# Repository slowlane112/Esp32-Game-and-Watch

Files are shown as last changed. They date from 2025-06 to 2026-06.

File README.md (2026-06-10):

# Esp32-Game-and-Watch

Esp32‑Game‑and‑Watch is a project for recreating classic Game & Watch handhelds using an ESP32 microcontroller, 3D‑printed cases, and simple electronics. 

It currently supports most single screen and multi screen Game & Watch titles, making it easy to recreate a wide range of the original handhelds.

## Latest Updates

- Updated the codebase to work with ESP‑IDF 6.0
- Added support for ST7789V LCD screens

<table>
<tr>
<td><strong>Demos</strong></td>
</tr>
<tr>
<td>
	<p><strong>Single Screen</strong></p>
	<p><a href="https://github.com/slowlane112/Esp32-Game-and-Watch/tree/main/gandw_demo_single_screen">
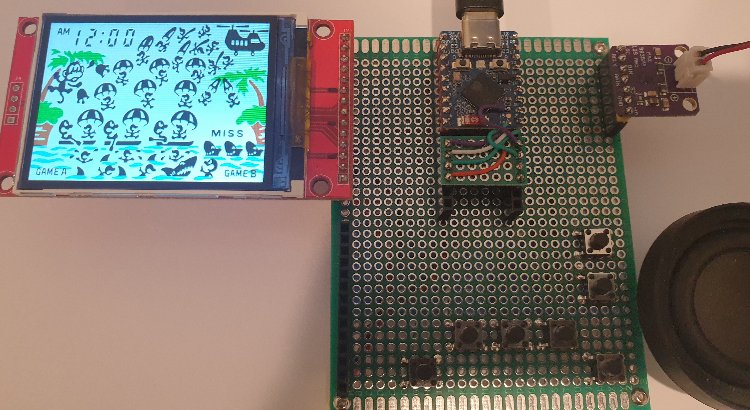
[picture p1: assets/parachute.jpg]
Parachute
		
	</a></p>
	<p><a href="https://github.com/slowlane112/Esp32-Game-and-Watch/tree/main/gandw_demo_single_screen">https://github.com/slowlane112/Esp32-Game-and-Watch/tree/main/gandw_demo_single_screen</a></p>
</td>
</tr>
<tr>
<td>
	<p><strong>Multi Screen</strong></p>
	<p><a href="https://github.com/slowlane112/Esp32-Game-and-Watch/tree/main/gandw_demo_multi_screen">
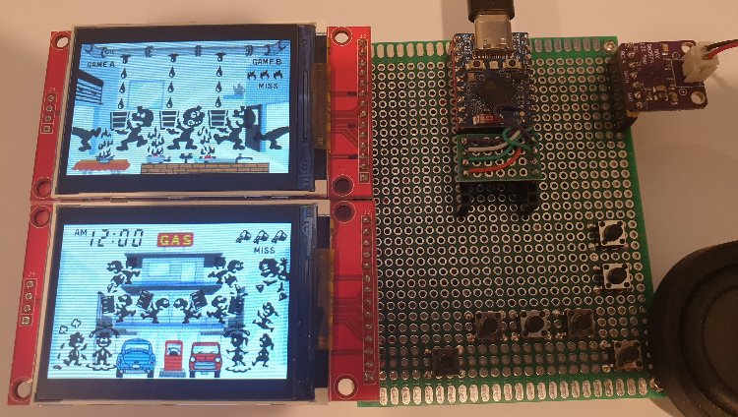
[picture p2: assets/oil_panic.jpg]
Oil Panic
		
	</a></p>
	<p><a href="https://github.com/slowlane112/Esp32-Game-and-Watch/tree/main/gandw_demo_multi_screen">https://github.com/slowlane112/Esp32-Game-and-Watch/tree/main/gandw_demo_multi_screen</a></p>
</td>	
</tr>
</table>

<br>

<table>
<tr>
<td><strong>Single Screen Handhelds</strong></td>
</tr>
<tr>
<td>
	<p><strong>2 Buttons</strong></p>
	<p><a href="https://github.com/slowlane112/Esp32-Game-and-Watch/tree/main/gandw_handheld/README-single_screen_2_button.md">
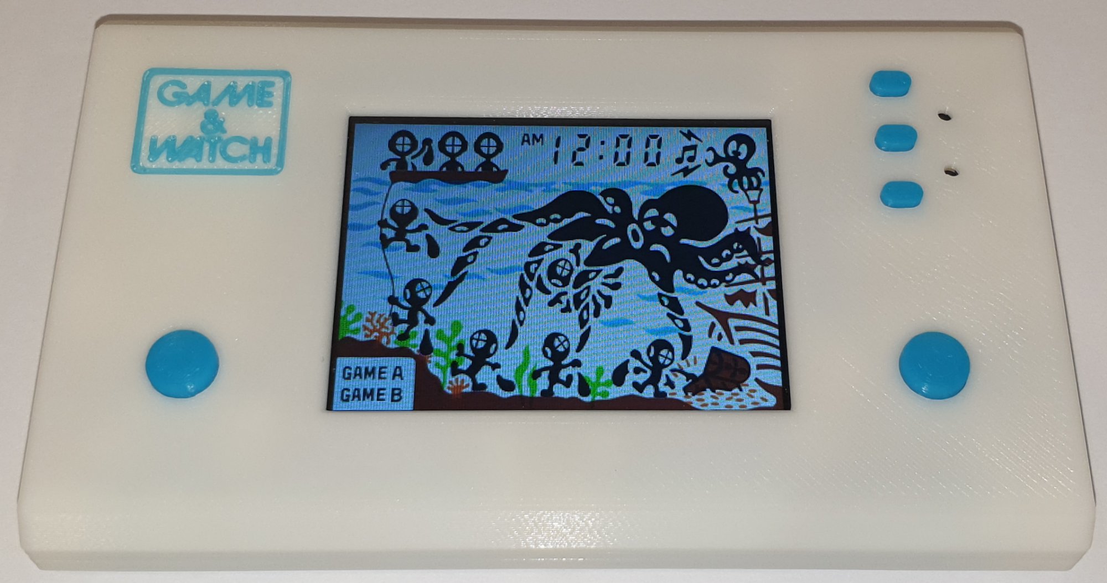
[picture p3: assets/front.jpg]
Single Screen Handheld
		
	</a></p>
	<p><a href="https://github.com/slowlane112/Esp32-Game-and-Watch/tree/main/gandw_handheld/README-single_screen_2_button.md">https://github.com/slowlane112/Esp32-Game-and-Watch/tree/main/gandw_handheld/README-single_screen_2_button.md</a></p>
</td>
</tr>
<tr>
<td>
	<p><strong>4 Buttons</strong></p>
	<p><a href="https://github.com/slowlane112/Esp32-Game-and-Watch/tree/main/gandw_handheld/README-single_screen_4_button.md">
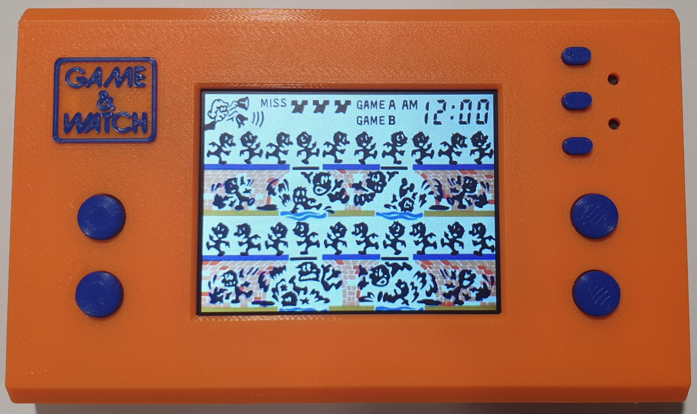
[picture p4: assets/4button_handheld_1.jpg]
Single Screen 4 Button Handheld
		
	</a></p>
	<p><a href="https://github.com/slowlane112/Esp32-Game-and-Watch/tree/main/gandw_handheld/README-single_screen_4_button.md">https://github.com/slowlane112/Esp32-Game-and-Watch/tree/main/gandw_handheld/README-single_screen_4_button.md</a></p>
</td>	
</tr>
</table>

<br>

<table>
<tr>
<td><strong>Multi Screen Handhelds</strong></td>
</tr>
<tr>
<td>
	<p><strong>2 Buttons</strong></p>
	<p><a href="https://github.com/slowlane112/Esp32-Game-and-Watch/tree/main/gandw_handheld/README-multi_screen_2_button.md">
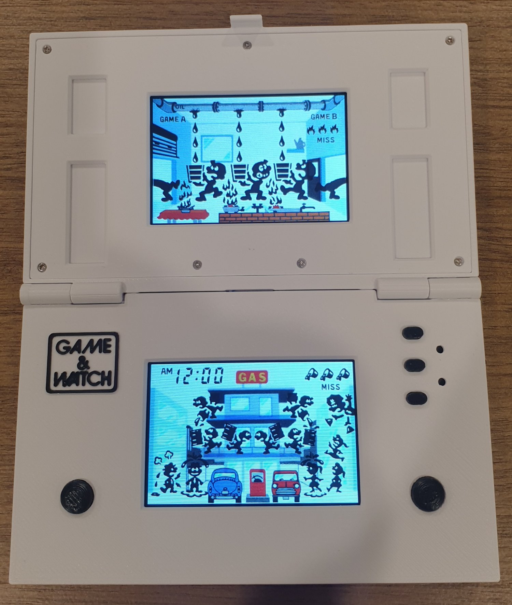
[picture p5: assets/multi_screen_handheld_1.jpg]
Multi Screen Handheld
    	
	</a></p>
	<p><a href="https://github.com/slowlane112/Esp32-Game-and-Watch/tree/main/gandw_handheld/README-multi_screen_2_button.md">https://github.com/slowlane112/Esp32-Game-and-Watch/tree/main/gandw_handheld/README-multi_screen_2_button.md</a></p>
</td>
</tr>
<tr>
<td>
	<p><strong>D-pad</strong></p>
	<p><a href="https://github.com/slowlane112/Esp32-Game-and-Watch/tree/main/gandw_handheld/README-multi_screen_dpad.md">
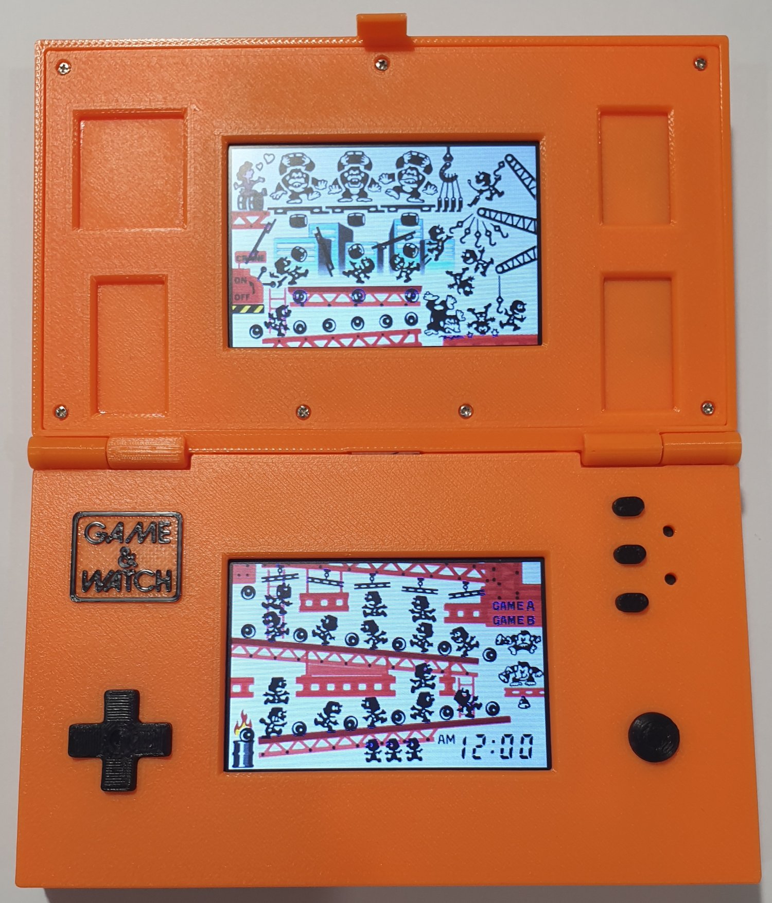
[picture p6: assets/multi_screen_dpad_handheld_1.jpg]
Multi Screen D-pad Handheld
    	
	</a></p>
	<p><a href="https://github.com/slowlane112/Esp32-Game-and-Watch/tree/main/gandw_handheld/README-multi_screen_dpad.md">https://github.com/slowlane112/Esp32-Game-and-Watch/tree/main/gandw_handheld/README-multi_screen_dpad.md</a></p>
</td>	
</tr>
</table>

<br>

<table>
<tr>
<td><strong>Cardputer</strong></td>
</tr>
<tr>
<td>
	<p><strong>Single Screen - Cardputer v1.1 and Cardputer Adv.</strong></p>
	<p><a href="https://github.com/slowlane112/Esp32-Game-and-Watch/tree/main/gandw_cardputer/README-cardputer.md">
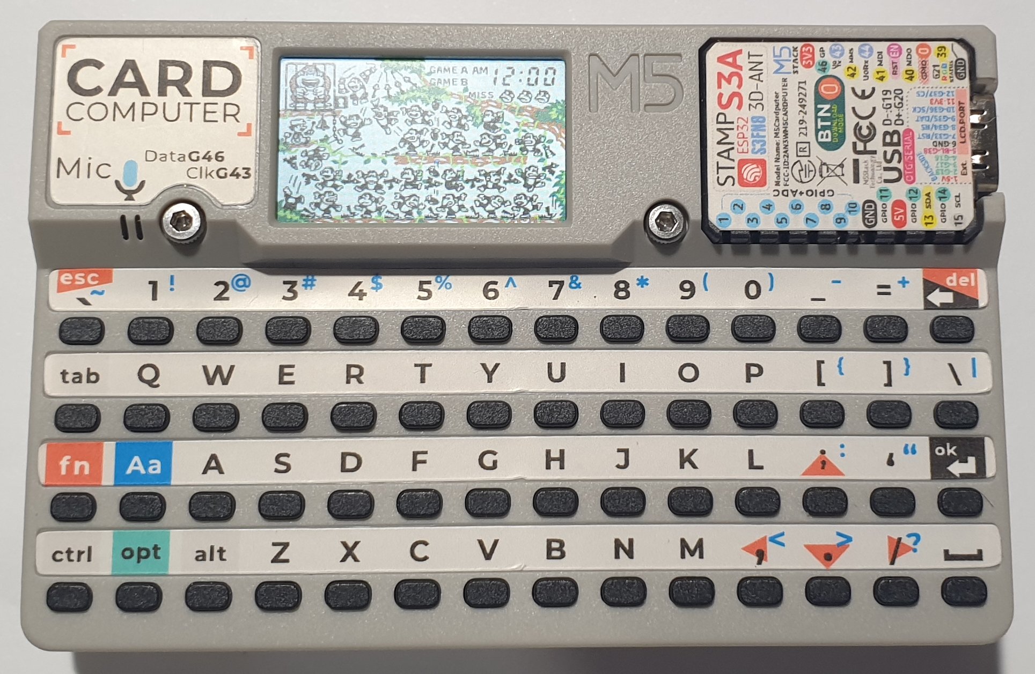
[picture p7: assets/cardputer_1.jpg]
Cardputer
    	
	</a></p>
	<p><a href="https://github.com/slowlane112/Esp32-Game-and-Watch/tree/main/gandw_cardputer/README-cardputer.md">https://github.com/slowlane112/Esp32-Game-and-Watch/tree/main/gandw_cardputer/README-cardputer.md</a></p>
</td>
</tr>
<tr>
<td>
	<p><strong>Multi Screen - Cardputer Adv.</strong></p>
	<p><a href="https://github.com/slowlane112/Esp32-Game-and-Watch/tree/main/gandw_cardputer/README-cardputer_multi_screen.md">
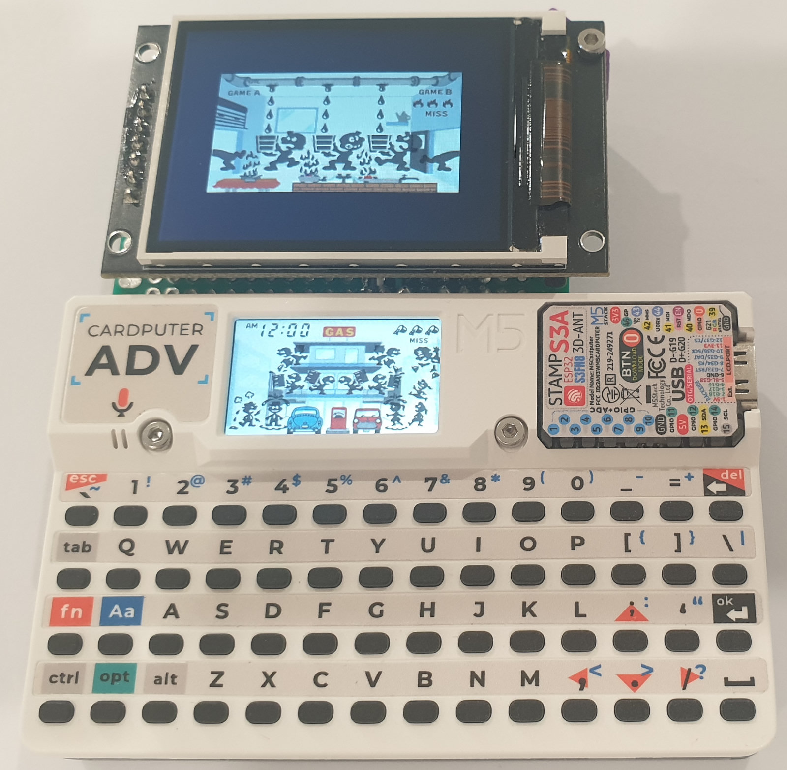
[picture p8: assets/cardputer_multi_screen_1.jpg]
Cardputer
    	
	</a></p>
	<p><a href="https://github.com/slowlane112/Esp32-Game-and-Watch/tree/main/gandw_cardputer/README-cardputer_multi_screen.md">https://github.com/slowlane112/Esp32-Game-and-Watch/tree/main/gandw_cardputer/README-cardputer_multi_screen.md</a></p>
</td>
</tr>
</table>

# Hardware Overview

## ESP32-S3

The project runs on an ESP32‑S3 development board. For handheld builds, the design uses the compact ESP32‑S3 Zero development board.

<table>
<tr>
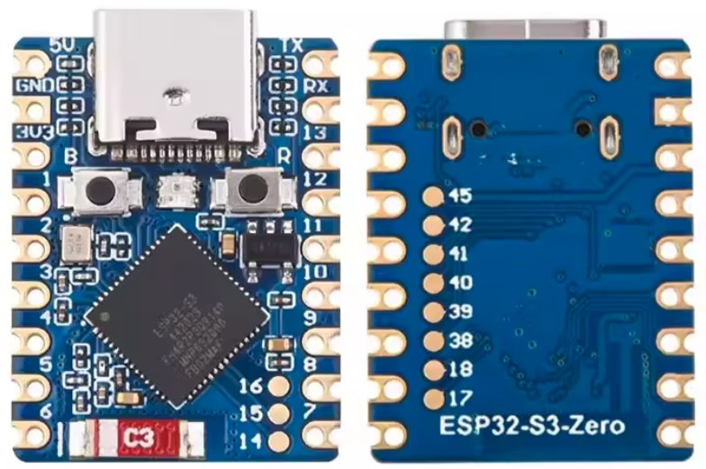
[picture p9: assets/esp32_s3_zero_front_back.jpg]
    <td></td>
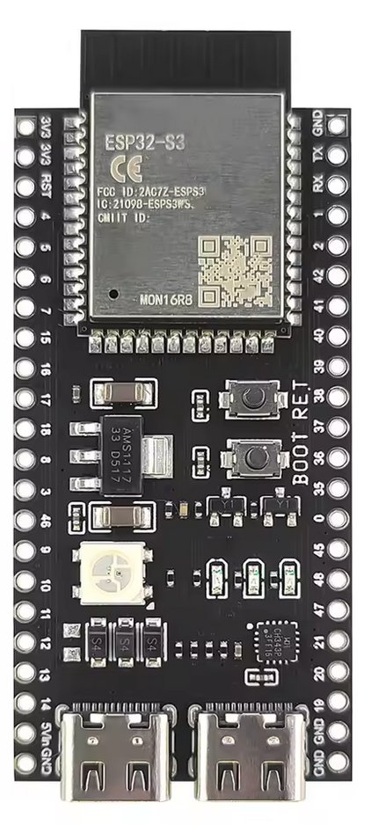
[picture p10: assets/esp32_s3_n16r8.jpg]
    <td></td>
</tr>
<tr>
    <td>ESP32-S3-Zero</td>
    <td>ESP32-S3 N16R8</td>
</tr>
</table>

## Displays

The project supports both the ILI9341 and the newer ST7789V displays. The ST7789V is generally preferred because it supports higher SPI clock speeds and its flex‑cable pin spacing is easier to solder.

<table>
<tr>
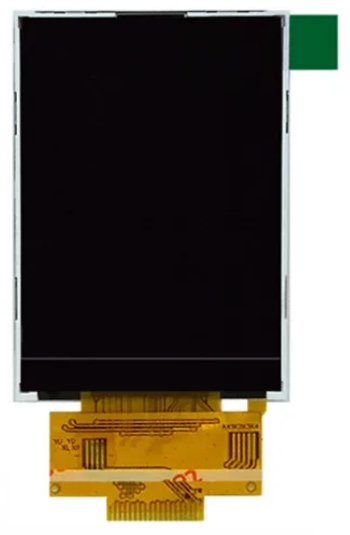
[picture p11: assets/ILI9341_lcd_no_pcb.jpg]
    <td></td>
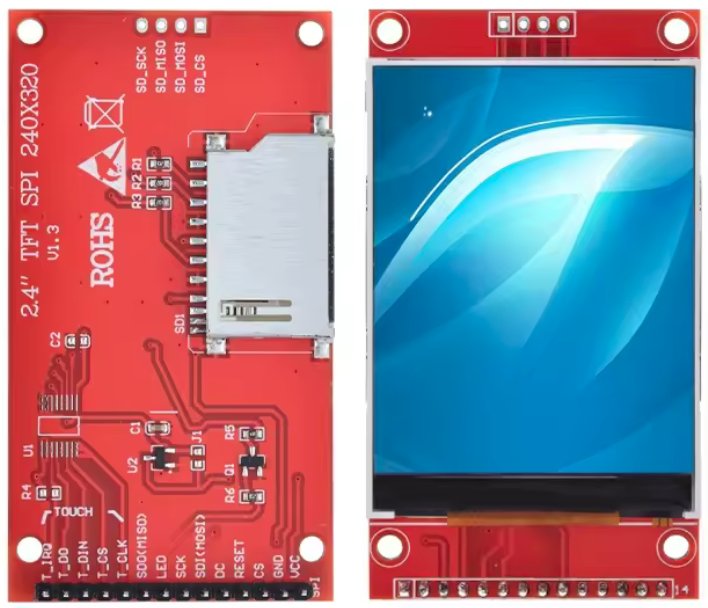
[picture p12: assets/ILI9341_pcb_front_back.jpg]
    <td></td>
</tr>
<tr>
    <td colspan="2">2.4 inch 240 * 320 ILI9341</td>
</tr>
</table>

<table>
<tr>
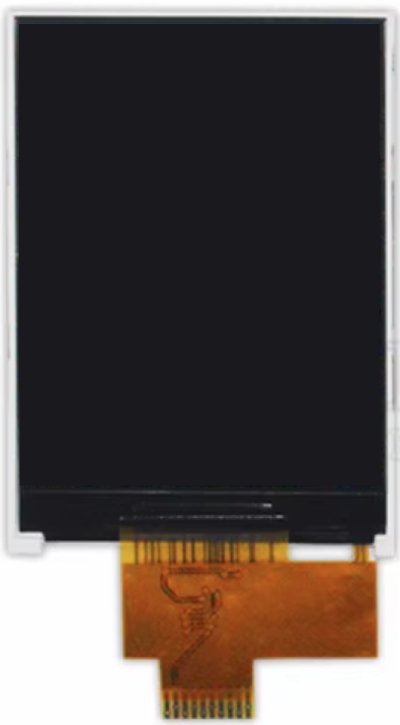
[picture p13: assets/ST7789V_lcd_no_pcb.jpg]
    <td></td>
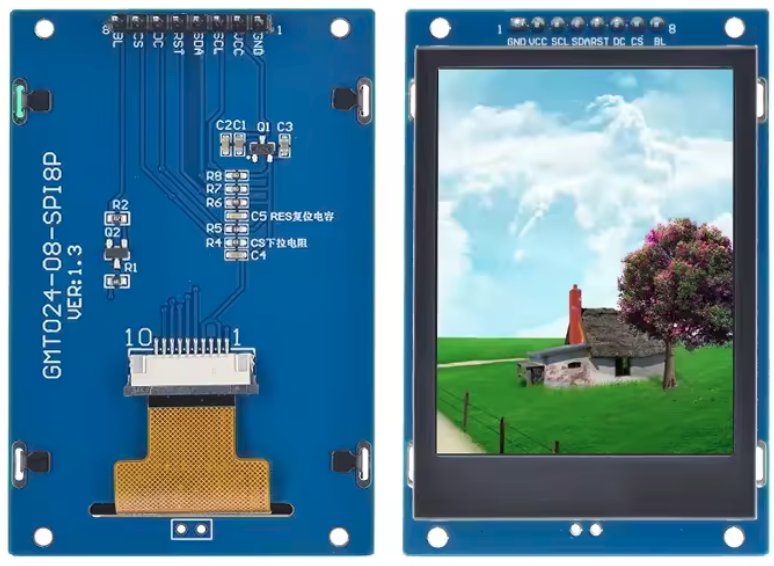
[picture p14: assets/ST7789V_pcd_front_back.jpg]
    <td></td>
</tr>
<tr>
    <td colspan="2">2.4 inch 240 * 320 ST7789V</td>
</tr>
</table>

## Audio

The MAX98357A digital I2S Audio Amplifier Module is used for sound.

<table>
<tr>
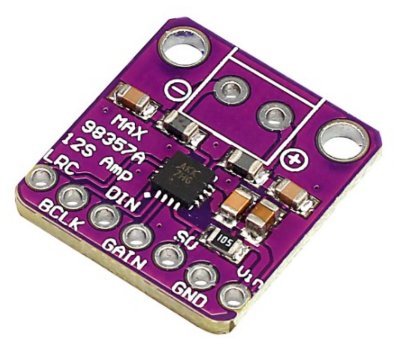
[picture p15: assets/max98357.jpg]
    <td></td>    
</tr>
</table>

# Acknowledgements

## LCD-Game-Emulator

https://github.com/bzhxx/lcd-game-emulator

## Retro-Go

https://github.com/ducalex/retro-go

The LCD-Game-Emulator version used by the project was copied from Retro-Go because it contains additional code to handle the loading of the gw files.

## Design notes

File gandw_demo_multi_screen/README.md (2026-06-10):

# Multi Screen Demo

A demo program using minimal code to run a multi screen game and watch rom on an esp32s3 via LCD Game Emulator.

Oil Panic

# Components
- ESP32-S3-Zero
- Lcd: 240x320 2.4 inch SPI panel with ILI9341 driver
- Audio: Max98357 I2S Amp
- Speaker
- Mini push Buttons

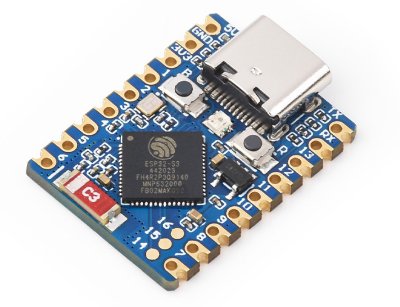
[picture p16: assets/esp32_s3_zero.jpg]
ESP32-S3-Zero

Max98357
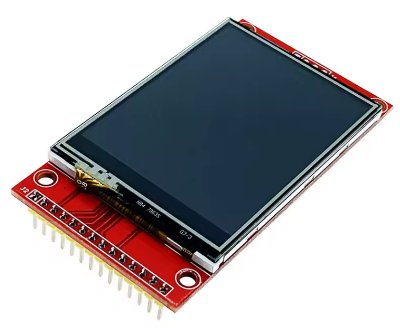
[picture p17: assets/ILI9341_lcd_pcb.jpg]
ILI9341 LCD with pcb

ILI9341 LCD without pcb

# Wiring

## LCD 1
- VCC:		ESP32 3.3v
- GND:		GND
- CS:		GND
- RESET:	GPIO 13
- DC:		GPIO 9
- MOSI:		GPIO 11
- SCK:		GPIO 12
- LED:		ESP32 3.3v

## LCD 2
- VCC:		ESP32 3.3v
- GND:		GND
- CS:		GND
- RESET:	GPIO 39
- DC:		GPIO 38
- MOSI:		GPIO 17
- SCK:		GPIO 18
- LED:		ESP32 3.3v

## Max98357
- VIN:		ESP32 3.3v
- GND:		GND
- LRC (WS):	GPIO 4    
- BCLK:		GPIO 10
- DIN:		GPIO 6

## Buttons
- GAME A:	GPIO 14
- GAME B:	GPIO 5
- TIME:		GPIO 3
- LEFT:		GPIO 2
- RIGHT:	GPIO 1
- ALARM:	GPIO 7
- ACL:		GPIO 8

# Screen Resolution
The ESP32-S3-Zero does not have enough memory to display 2 screens at 320 x 240 resolution.

It does have enough memory to display 2 screens at 320 x 210 resolution.

This is closer to the aspect ratio of the original multi screen game and watch games and what i have used in this project.

This makes the total resolution 320 x 420.

# Roms
The roms must be in .gw format.

These can be created using LCD-Game-Shrinker.

https://github.com/bzhxx/LCD-Game-Shrinker

Below is a link to a guide describing how to use LCD-Game-Shrinker to generate the files.

https://gist.github.com/DNA64/16fed499d6bd4664b78b4c0a9638e4ef

## Additional Steps for Multi Screen Games

LCD Game Shrinker will convert multi screen games into one screen games in portrait mode, so we need to do some additional steps when generating the gw files.

Below are instructions to fix oil panic. All other multi screen games will be similar.

Make a copy of LCD-Game-Shrinker to use for multi screen games.

In the file shrink_it.py set: 
```
gw_height=420
```
In the custom directory, edit gnw_opanic.py

set rom.rotate to false
```
rom.rotate = False
```
Change rom.width_border_ratio from:
```
rom.width_border_ratio = 10/100
```
to:
```
rom.width_border_ratio = 0
```

## Black border between screens
If you run LCD Game Shrinker now there will be a black bar of about 10 pixels between the top and bottom screen.
The gw file will still work ok, but it is a good idea to remove it as it is wasting 10 pixels from the display.

To remove the black bar you need to:

- Extract the artwork zip file.
- Edit the default.lay file to remove the black bar.
- Zip the files again with the updated default.lay file.

In the default.lay file, find the view with the Backgrounds Only. (They usually have a height of 1669).

There is usually more than 1 background view. I am not sure which view LCD Game Shrinker uses so i was just updating all of them. They all use that same values so it is quick to update all of them at the same time.

```
<view name="Backgrounds Only">

<bounds x="32" y="33" width="1296" height="1669" />
	
	<element ref="Screen-Top">					<bounds x="32" y="33" width="1296" height="817" /></element>
	<screen index="0" blend="multiply">			<bounds x="1" y="9" width="1349" height="899" /></screen>
	<element ref="Screen-Top">					<bounds x="32" y="33" width="1296" height="817" /><color alpha="0.0" /></element>
	
	<element ref="Screen-Bottom">				<bounds x="32" y="885" width="1296" height="817" /></element>
	<screen index="1" blend="multiply">			<bounds x="-1" y="903" width="1371" height="878" /></screen>
	<element ref="Screen-Bottom">				<bounds x="32" y="885" width="1296" height="817" /><color alpha="0.00" /></element>
	<element ref="Balcony">				<bounds x="32" y="885" width="1296" height="817" /><color alpha="0.5" /></element>

</view>
```

New height: (Screen-Top + Screen-Bottom) 817 + 817 = 1634

Height difference: 1669 - 1634 = 35

Bounds height attribute is updated with the new height.

The height difference is removed from the y attribute of all the bottom screen elements.

```
<view name="Backgrounds Only">

<bounds x="32" y="33" width="1296" height="1634" />
	
	<element ref="Screen-Top">					<bounds x="32" y="33" width="1296" height="817" /></element>
	<screen index="0" blend="multiply">			<bounds x="1" y="9" width="1349" height="899" /></screen>
	<element ref="Screen-Top">					<bounds x="32" y="33" width="1296" height="817" /><color alpha="0.0" /></element>
	
	<element ref="Screen-Bottom">				<bounds x="32" y="850" width="1296" height="817" /></element>
	<screen index="1" blend="multiply">			<bounds x="-1" y="868" width="1371" height="878" /></screen>
	<element ref="Screen-Bottom">				<bounds x="32" y="850" width="1296" height="817" /><color alpha="0.00" /></element>
	<element ref="Balcony">				<bounds x="32" y="850" width="1296" height="817" /><color alpha="0.5" /></element>

</view>
```

# Building
Install the ESP-IDF framework. Current version is v6.0.1.
https://docs.espressif.com/projects/esp-idf/en/stable/esp32s3/get-started/index.html

Make sure you can build the hello_world example project.

Download the code from this repo.

Use LCD-Game-Shrinker to generate a rom file for oil panic. Rename the file to gnwoilpanic.gw, and place the file in the /gandw_demo_multi_screen/main/ directory.

Go back to /gandw_demo_multi_screen/ directory and open the terminal or cmd window in this directory.

## Linux
These instructions are for linux. If you are using windows follow the same steps you did when building the hello_world example project.

Run the export.sh script or get_idf if you set it up.

Export script should be similar to: 

```
. $HOME/esp/esp-idf/export.sh
```

Build: 

```
idf.py build
```

Then: 

```
idf.py -p /dev/ttyACM0 flash
```

You can also monitor by adding monitor at the end: 

```
idf.py -p /dev/ttyACM0 flash monitor 
```

Press Ctrl and ] to exit monitor.

If you are getting errors try a fullclean before building: 

```
idf.py fullclean
```

# Esp32
The code has been setup to run on a ESP32-S3-Zero dev board.

If you are using another ESP32-S3 you will need to setup PSRAM for your device and maybe alter the GPIO's used.

For the ESP32-S3-WROOM1 dev board you can setup PSRAM using 
```
idf.py menuconfig
```
Go to Component config → ESP PSRAM → Support for external, SPI-connected RAM → SPI RAM config
 and enable Octal Mode PSRAM.

# LCD Display

## ST7789V Display

If using a ST7789V display, comment the ili9341 section in main.c and uncomment the st7789 section.

## Orientation

In the setup_lcd_spi function, there are 2 commands that you can use to change the screen orientation.

- esp_lcd_panel_swap_xy
- esp_lcd_panel_mirror

## Pixel Data

All the lcd panels i used required the pixel data to be byte swapped for the image to be displayed correctly.

I have swapped the byte order for the background and segment pixel data in lcd game emulator.

If the image displayed on your screen looks incorrect (wrong colours) you can change the byte swap setting.

In the file: /components/lcd_game_emulator/src/gw_sys/gw_system.h, set BYTE_SWAP to 0.

```
#define BYTE_SWAP 0
```

# Audio

The volume level can be altered by a changing the value of the sample variable.

```
if (gw_audio_buffer[i] > 0) {
    sample = 2000;
}
```

# Acknowledgements

## LCD-Game-Emulator
https://github.com/bzhxx/lcd-game-emulator

## Retro-Go
https://github.com/ducalex/retro-go

The LCD-Game-Emulator version used by the project was copied from Retro-Go because it contains additional code to handle the loading of the gw files.

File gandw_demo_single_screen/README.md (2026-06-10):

# Single Screen Demo

A demo program using minimal code to run a single screen game and watch rom on an esp32s3 via LCD Game Emulator.

Parachute

# Components
- ESP32-S3-Zero
- Lcd: 240x320 2.4 inch SPI panel with ILI9341 or ST7789V driver
- Audio: Max98357 I2S Amp
- Speaker
- Mini push Buttons

ESP32-S3-Zero
Max98357
ILI9341 LCD with pcb
ILI9341 LCD without pcb

# Wiring

## LCD
- VCC:		ESP32 3.3v
- GND:		GND
- CS:		GND
- RESET:	GPIO 13
- DC:		GPIO 9
- MOSI:		GPIO 11
- SCK:		GPIO 12
- LED:		ESP32 3.3v

## Max98357
- VIN:		ESP32 3.3v
- GND:		GND
- LRC (WS):	GPIO 4    
- BCLK:		GPIO 10
- DIN:		GPIO 6

## Buttons
- GAME A:	GPIO 14
- GAME B:	GPIO 5
- TIME:		GPIO 3
- LEFT:		GPIO 2
- RIGHT:	GPIO 1
- ALARM:	GPIO 7
- ACL:		GPIO 8

# Roms
The roms must be in .gw format.

These can be created using LCD-Game-Shrinker.

https://github.com/bzhxx/LCD-Game-Shrinker

Below is a link to a guide describing how to use LCD-Game-Shrinker to generate the files.

https://gist.github.com/DNA64/16fed499d6bd4664b78b4c0a9638e4ef

# Building
Install the ESP-IDF framework. Current version is v6.0.1.
https://docs.espressif.com/projects/esp-idf/en/stable/esp32s3/get-started/index.html

Make sure you can build the hello_world example project.

Download the code from this repo.

Use LCD-Game-Shrinker to generate a rom file for parachute. Rename the file to gnwparachute.gw, and place the file in the /gandw_demo_single_screen/main/ directory.

Go back to /gandw_demo_single_screen/ directory and open the terminal or cmd window in this directory.

## Linux

These instructions are for linux. If you are using windows follow the same steps you did when building the hello_world example project.

Run the export.sh script or get_idf if you set it up.

Export script should be similar to: 

```
. $HOME/esp/esp-idf/export.sh
```

Build: 

```
idf.py build
```

Then: 

```
idf.py -p /dev/ttyACM0 flash
```

You can also monitor by adding monitor at the end: 

```
idf.py -p /dev/ttyACM0 flash monitor 
```

Press Ctrl and ] to exit monitor.

If you are getting errors try a fullclean before building: 

```
idf.py fullclean
```

# Esp32
The code has been setup to run on a ESP32-S3-Zero dev board.

If you are using another ESP32-S3 you will need to setup PSRAM for your device and maybe alter the GPIO's used.

For the ESP32-S3-WROOM1 dev board you can setup PSRAM using 
```
idf.py menuconfig
```
Go to Component config → ESP PSRAM → Support for external, SPI-connected RAM → SPI RAM config
 and enable Octal Mode PSRAM.

# LCD Display

## ST7789V Display

If using a ST7789V display, comment the ili9341 section in main.c and uncomment the st7789 section.

## Orientation

In the setup_lcd_spi function, there are 2 commands that you can use to change the screen orientation.

- esp_lcd_panel_swap_xy
- esp_lcd_panel_mirror

## Pixel Data

All the lcd panels i used required the pixel data to be byte swapped for the image to be displayed correctly.

I have swapped the byte order for the background and segment pixel data in lcd game emulator.

If the image displayed on your screen looks incorrect (wrong colours) you can change the byte swap setting.

In the file: /components/lcd_game_emulator/src/gw_sys/gw_system.h, set BYTE_SWAP to 0.

```
#define BYTE_SWAP 0
```

# Audio

The volume level can be altered by a changing the value of the sample variable.

```
if (gw_audio_buffer[i] > 0) {
    sample = 2000;
}
```

# Acknowledgements

## LCD-Game-Emulator
https://github.com/bzhxx/lcd-game-emulator

## Retro-Go
https://github.com/ducalex/retro-go

The LCD-Game-Emulator version used by the project was copied from Retro-Go because it contains additional code to handle the loading of the gw files.

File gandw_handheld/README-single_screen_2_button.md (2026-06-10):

# Single Screen Handheld

# Disclaimer: 

This project is a work in progress.

I assume no responsibility or liability for any errors, omissions, or outcomes resulting from the use of the information provided within this project.

You are strongly advised to conduct your own thorough research and ensure you have a comprehensive understanding of best practices for the safe charging and handling of Li-ion batteries. Improper handling can lead to serious risks, including but not limited to fire, explosion, or personal injury.

Use the information provided in this project at your own risk.

<table>
<tr><td colspan="2">Front</td></tr>
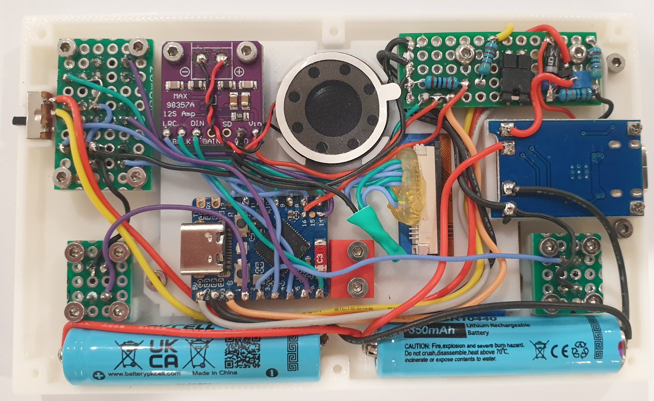
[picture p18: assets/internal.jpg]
Internal
<tr><td colspan="2"></td></tr>
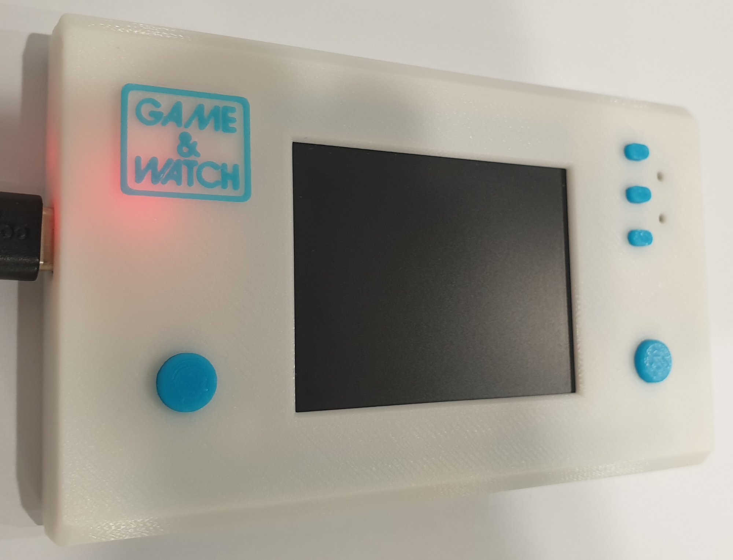
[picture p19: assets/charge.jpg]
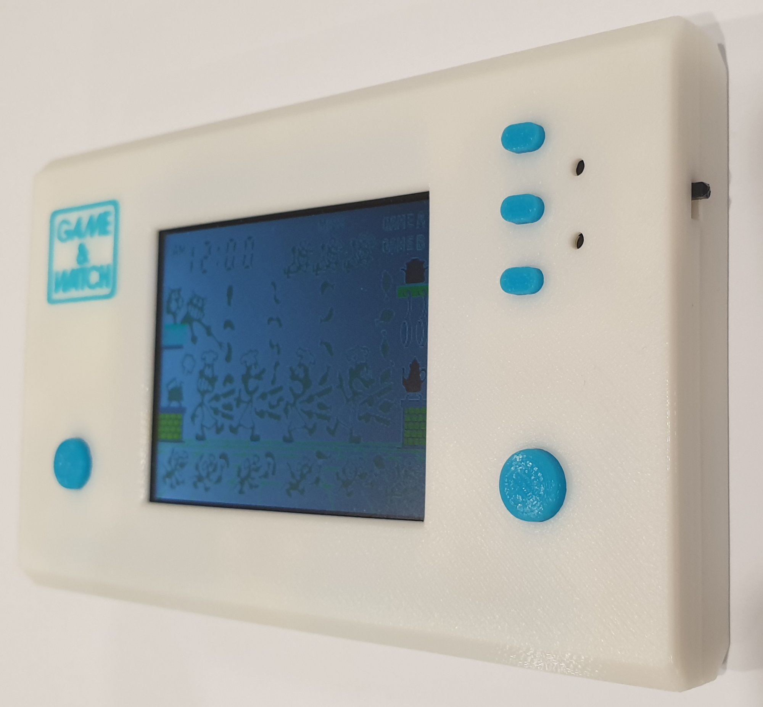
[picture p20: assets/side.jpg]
<tr><td></td><td></td></tr>
</table>

# Features

## 12 Games
Plays 12 two button game and watch games.<br>
Use the left and right buttons in the menu to select a game, then press Game A to start the game.<br>
You can return to the menu by pressing the left and right buttons for a few seconds.<br>

## Volume Adjustment
Volume adjustment with on screen display.<br>
Volume down: Time and Left buttons.<br>
Volume up: Time and Right buttons.<br>
Remembers volume level on power up.

## Power
Two 10440 batteries, USB-C charging and on/off switch.

## Battery Level Indicator
Battery level is displayed on power up.

# Components
- ESP32-S3-Zero
- Display: 2.4 inch SPI panel 240x320 LCD with ILI9341 or ST7789V driver
  (No board - LCD only, No Touch. AliExpress seller: XunMing Store)
- Audio: Max98357 I2S Amp
- Speaker: 20mm
- USB-C TP4056 Battery Charger Module 
- 2 x 10440 Li-ion batteries
- Mini Push Buttons 4.5mm x 4.5mm x 3.8mm
- 3mm SS12d00 mini slide switch.
- AO3401A mosfet
- 1N5817 schottky diode
- Resistors: 2 x 4.7K, 10K and 100K
- Screws M2 - 4mm, 6mm and 8mm long.
- Screws to mount the TP4056 module. 2 x M1.5

<table>
<tr>
    <td></td>
    <td></td>
    <td></td>    
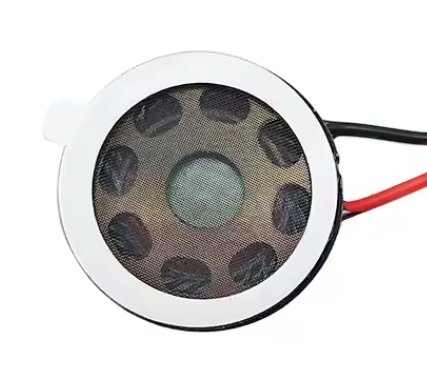
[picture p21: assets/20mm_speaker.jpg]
    <td></td>
</tr>
</table>

<table>
<tr>
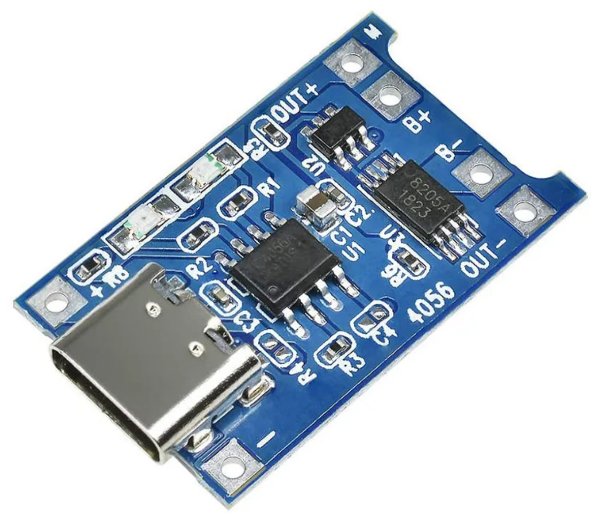
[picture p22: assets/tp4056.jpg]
    <td></td>
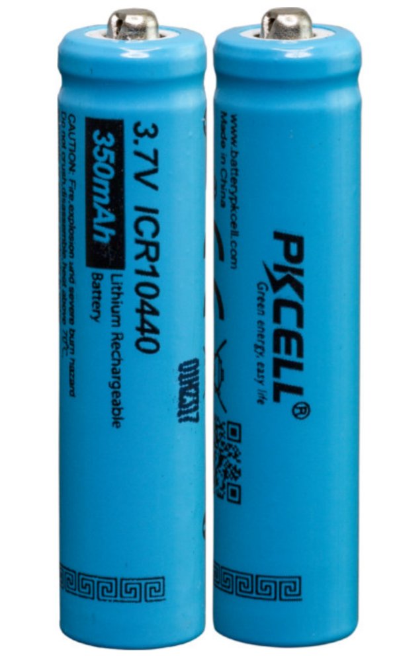
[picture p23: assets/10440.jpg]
    <td></td>
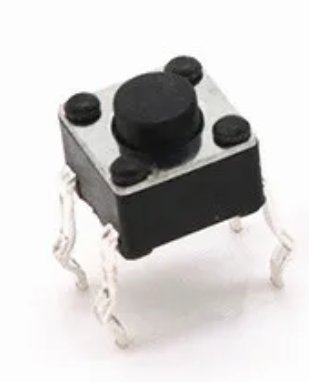
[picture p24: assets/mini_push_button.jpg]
    <td></td>
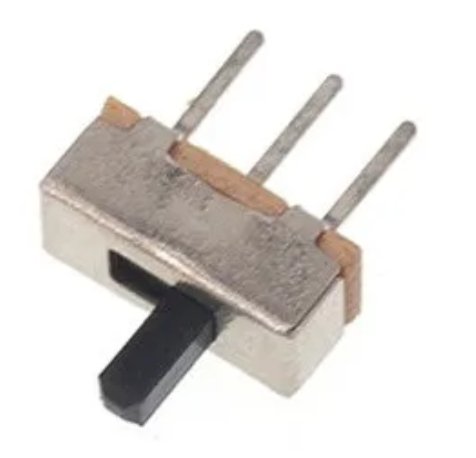
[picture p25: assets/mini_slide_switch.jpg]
    <td></td>
</tr>
</table>

# Power

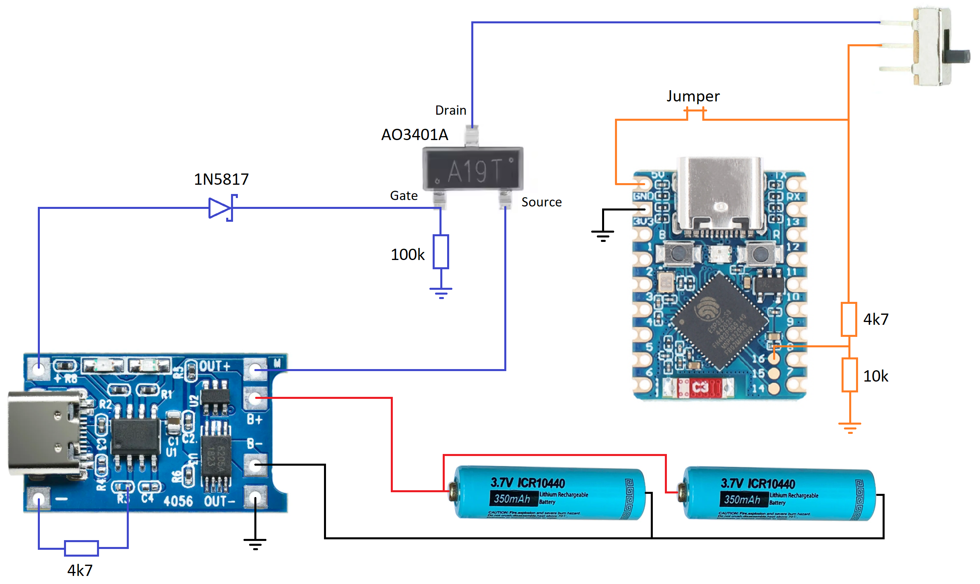
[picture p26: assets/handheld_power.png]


## TP4056

A TP4056 module is used to charge the battery. These modules are designed for charging 18650 batteries at 1A.

To charge 10440 batteries, resistor R3 should be replaced with a 4.7kΩ resistor. This will charge the battery at approximately 250mA. To make it easier, after removing resistor R3, you can connect a wire to pin 2 of the main IC and mount the 4.7kΩ resistor on a perfboard with the other end connected to ground.

A mosfet (AO3401A) is used to disconnect the load from the battery while it is charging. This can be skipped if you remember to always turn off the device when it is charging. If you plan on using the mosfet, to make it easier you can connect a wire to pin 4 of the main IC and connect the other end to the schottky diode leading to the mosfet gate.

The TP4056 can only be mounted via the holes in the USB voltage pads. When you insert a screw into the pads it might break the connection between the top and bottom pads. If you plan to use these pads check to make sure the connection is not broken after you screw them in place.

## Battery Level Indicator

The battery voltage is sent to GPIO 16 for a battery level indicator. The ESP32-S3 ADC can measure voltages up to 3.1V so a voltage divider is used to drop the voltage to a suitable level.

With a few changes, the AO3401A mosfet can be setup to power the load from USB power while the battery is changing, however if you choose to do this you will also need to alter the voltage divider values to make sure the voltage at GPIO 16 does not exceed 3.1V.

## Jumper

A jumper has been placed between the ESP32 5v pin and the switch. This jumper should be open when connecting the ESP32 to USB for debugging. Failure to open the jumper will result in voltage from ESP32 making its way to the batteries if the switch is also turned on. You could skip the jumper installation, and always make sure the switch is off when debugging, but you will need the jumper installed and open if you want to debug the battery level indicator code.

## 3D Files

View 3D files: [Single Screen Handheld 3D Files](../assets/3d_files/gandw_single_screen_handheld/)

## Button Circuit Boards

The buttons need to be mounted on 2.54mm pitch perfboard. 

The alarm and ACL buttons need to be mounted slightly high on the board. Use the spacer (alarm_acl_button_spacer.stl) to mount them at the correct height.

The diagrams below show how to mount the buttons:

<table>
<tr>
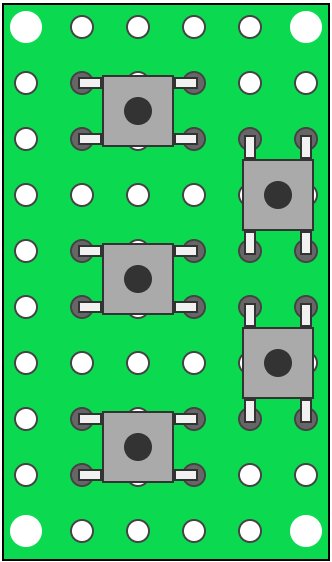
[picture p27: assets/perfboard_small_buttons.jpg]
    <td></td>
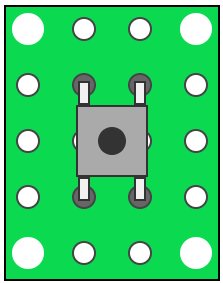
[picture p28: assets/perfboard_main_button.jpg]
    <td></td>
</tr>
</table>

# Wiring

## LCD
- VCC:        ESP32 3.3v
- GND:        GND
- CS:         GND
- RESET:      GPIO 13
- DC:         GPIO 9
- MOSI        GPIO 11
- SCK:        GPIO 12
- LEDA:       ESP32 3.3v
- LEDK1:      GND  

## Max98357
- VIN:        ESP32 3.3v
- GND:        GND
- LRC (WS):   GPIO 4    
- BCLK:       GPIO 10
- DIN:        GPIO 6

## Buttons
- GAME A:       GPIO 14
- GAME B:       GPIO 5
- TIME:         GPIO 3
- LEFT:         GPIO 2
- RIGHT:        GPIO 1
- ALARM:        GPIO 7
- ACL:          GPIO 8

## Battery Level
- Battery +:   GPIO 16 (via voltage divider)

# Roms

The roms must be in .gw format.

These can be created using LCD-Game-Shrinker.

https://github.com/bzhxx/LCD-Game-Shrinker

Below is a link to a guide describing how to use LCD-Game-Shrinker to generate the files.

https://gist.github.com/DNA64/16fed499d6bd4664b78b4c0a9638e4ef

Below is a list of the gw files required:

<table cellpadding="2" cellspacing="0">
<tr><td>Mame Rom</td><td>GW File</td></tr>
<tr><td>gnw_pchute</td><td>Game & Watch Parachute.gw</td></tr>
<tr><td>gnw_octopus</td><td>Game & Watch Octopus.gw</td></tr>
<tr><td>gnw_fire</td><td>Game & Watch Fire (Wide Screen).gw</td></tr>
<tr><td>gnw_chef</td><td>Game & Watch Chef.gw</td></tr>
<tr><td>gnw_popeye</td><td>Game & Watch Popeye (Wide Screen).gw</td></tr>
<tr><td>gnw_tbridge</td><td>Game & Watch Turtle Bridge.gw</td></tr>
<tr><td>gnw_vermin</td><td>Game & Watch Vermin.gw</td></tr>
<tr><td>gnw_ball</td><td>Game & Watch Ball.gw</td></tr>
<tr><td>gnw_fires</td><td>Game & Watch Fire (Silver).gw</td></tr>
<tr><td>gnw_helmet</td><td>Game & Watch Helmet (CN-17 version).gw</td></tr>
<tr><td>gnw_mariotj</td><td>Game & Watch Mario The Juggler.gw</td></tr>
<tr><td>gnw_tfish</td><td>Game & Watch Tropical Fish.gw</td></tr>
</table>

# Building
Install the ESP-IDF framework. The version I used was v6.0.1.
https://docs.espressif.com/projects/esp-idf/en/stable/esp32s3/get-started/index.html

Make sure you can build the hello_world example project.

Download the code from this repo.

Use LCD-Game-Shrinker to generate a game files (see above) and place the gw files in the /gandw_handheld/main/ directory.

Go back to /gandw_handheld/ directory and open the terminal or cmd window in this directory.

## Linux

These instructions are for linux. If you are using windows follow the same steps you did when building the hello_world example project.

Run the export.sh script or get_idf if you set it up.

Export script should be similar to: 

```
. $HOME/esp/esp-idf/export.sh
```

Build: 

```
idf.py build
```

Then: 

```
idf.py -DDISPLAY=ili9341 -DMODEL=single_screen_2_button -p /dev/ttyACM0 flash
```

or

```
idf.py -DDISPLAY=st7789 -DMODEL=single_screen_2_button -p /dev/ttyACM0 flash
```

You can also monitor by adding monitor at the end: 

```
idf.py -DMODEL=single_screen_2_button -p /dev/ttyACM0 flash monitor 
```

Press Ctrl and ] to exit monitor.

If you are getting errors try a fullclean before building: 

```
idf.py fullclean
```

# LCD Display

## Orientation

In the display.c source file, there are 2 commands that you can use to change the screen orientation.

- esp_lcd_panel_swap_xy
- esp_lcd_panel_mirror

## Pixel Data

All the lcd panels i used required the pixel data to be byte swapped for the image to be displayed correctly.

I have swapped the byte order for the background and segment pixel data in lcd game emulator.

If the image displayed on your screen looks incorrect (wrong colours) you can change the byte swap setting.

In the file: /components/lcd_game_emulator/src/gw_sys/gw_system.h, set BYTE_SWAP to 0.

```
#define BYTE_SWAP 0
```

# Acknowledgements

## LCD-Game-Emulator
https://github.com/bzhxx/lcd-game-emulator

## Retro-Go
https://github.com/ducalex/retro-go

The LCD-Game-Emulator version used by the project was copied from Retro-Go because it contains additional code to handle the loading of the gw files.

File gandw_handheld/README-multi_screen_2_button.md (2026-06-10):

# Multi Screen 2 Button Handheld

# Disclaimer:

This project is a work in progress.

I assume no responsibility or liability for any errors, omissions, or outcomes resulting from the use of the information provided within this project.

You are strongly advised to conduct your own thorough research and ensure you have a comprehensive understanding of best practices for the safe charging and handling of Li-ion batteries. Improper handling can lead to serious risks, including but not limited to fire, explosion, or personal injury.

Use the information provided in this project at your own risk.

<table>
<tr>
    <td>Front</td>
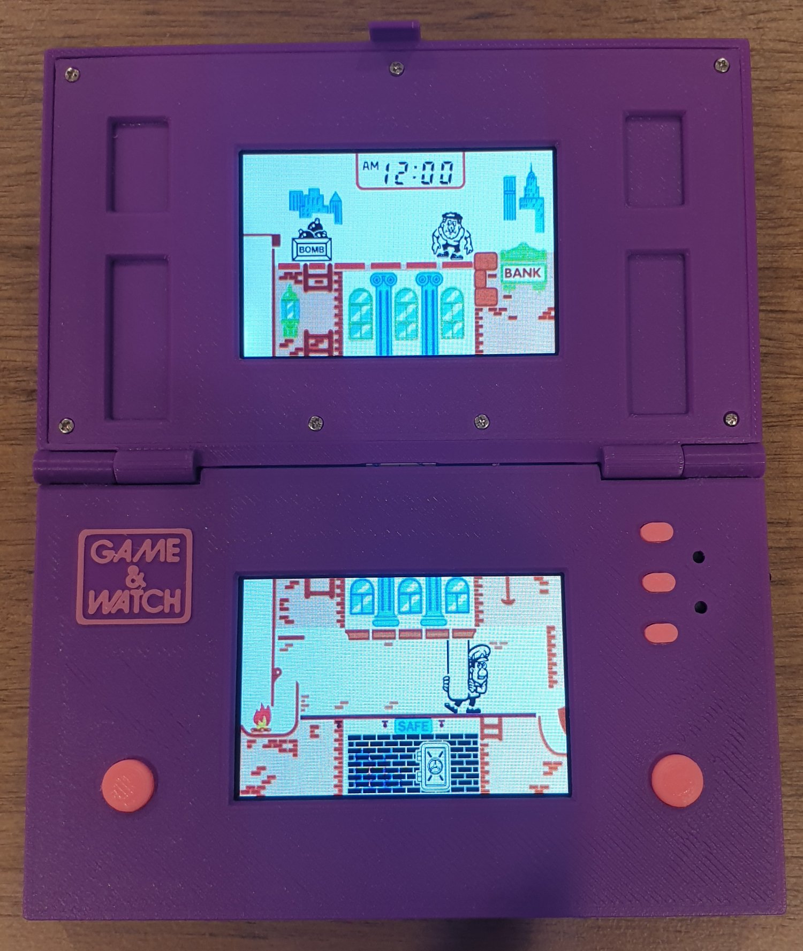
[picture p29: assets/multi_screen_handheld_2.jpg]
    <td></td>
</tr>
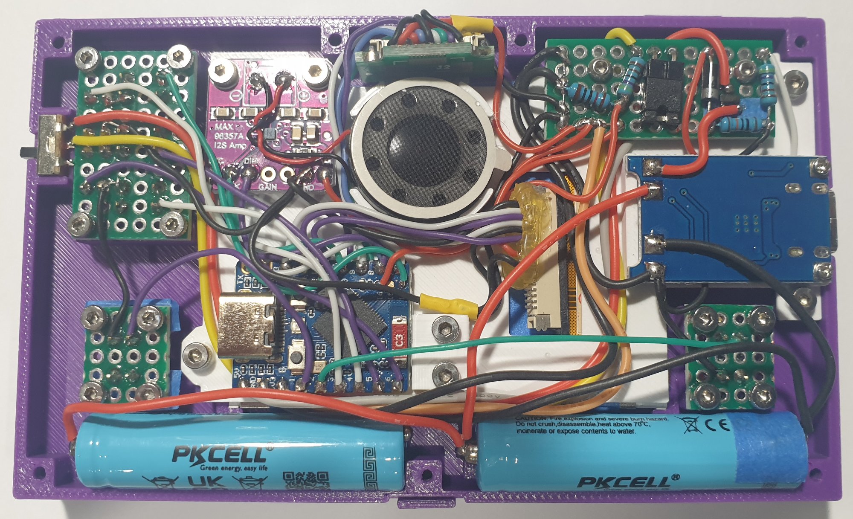
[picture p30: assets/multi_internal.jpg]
Internal
<tr><td colspan="2"></td></tr>
<tr>
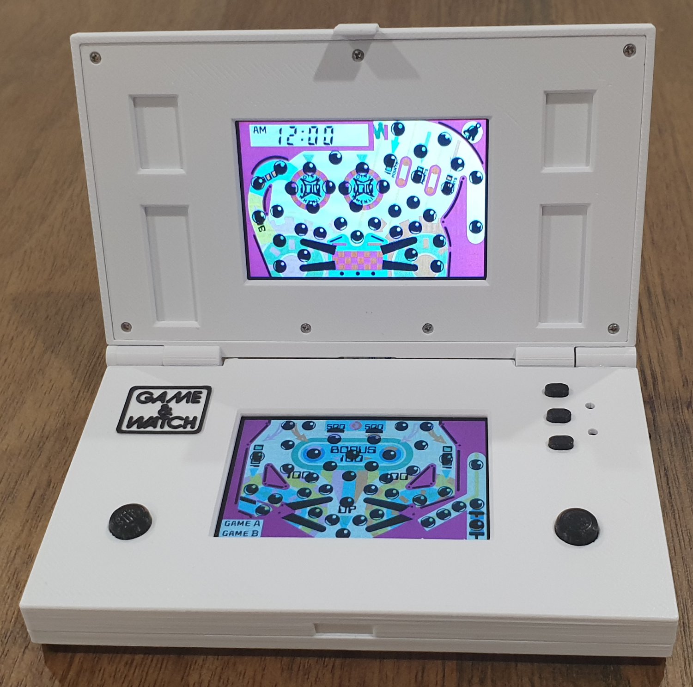
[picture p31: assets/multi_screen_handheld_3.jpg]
Side
    <td></td>
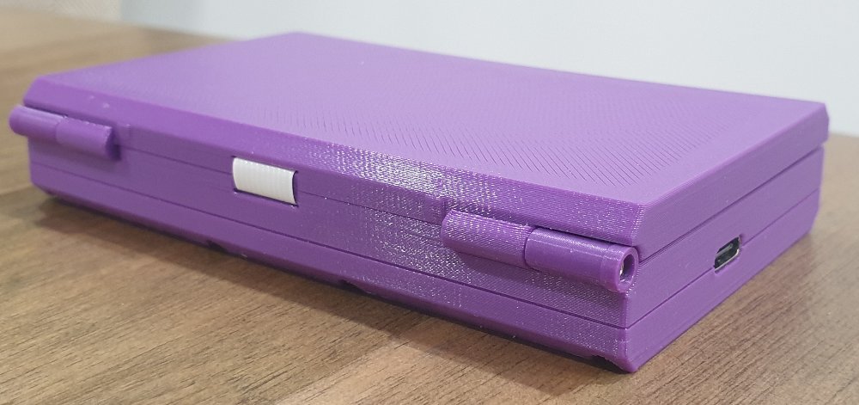
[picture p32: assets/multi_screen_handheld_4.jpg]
Back
    <td></td>
</tr>
</table>

# Features

Plays 3 two button multi screen game and watch games.

Use the left and right buttons in the menu to select a game, then press Game A to start the game.

You can return to the menu by pressing the left and right buttons for a few seconds.

## Volume Adjustment

Volume adjustment with on screen display.<br>
Volume down: Time and Left buttons.<br>
Volume up: Time and Right buttons.<br>
Remembers volume level on power up.

## Power

Two 10440 batteries, USB-C charging and on/off switch.

## Battery Level Indicator

Battery level is displayed on power up.

# Components

- ESP32-S3-Zero
- Display: 2 x 2.4 inch SPI panel 240x320 LCD with ILI9341 or ST7789V driver
  (No board - LCD only, No Touch. AliExpress seller: XunMing Store)
- Audio: Max98357 I2S Amp
- Speaker: 20mm
- USB-C TP4056 Battery Charger Module 
- 2 x 10440 Li-ion batteries
- Mini Push Buttons 4.5mm x 4.5mm x 3.8mm
- 3mm SS12d00 mini slide switch.
- AO3401A mosfet
- 1N5817 schottky diode
- 10cm FFC Flexible Flat Ribbon Cable - 1.0mm Pitch 10 Pin.
- FFC FPC connector adapter board. 10P - 1mm pitch.
- Resistors: 2 x 4.7K, 10K and 100K
- Screws M2 - 4mm, 6mm and 8mm long.
- Screws to mount the TP4056 module. 2 x M1.5
- Screws to mount the top display. 7 x M1.5 3mm long.
- Hinge screws: M2 x 20mm long

<table>
<tr>
    <td></td>
    <td></td>
    <td></td>    
    <td></td>
    <td></td>
</tr>
</table>

<table>
<tr>
    <td></td>
    <td></td>
    <td></td>
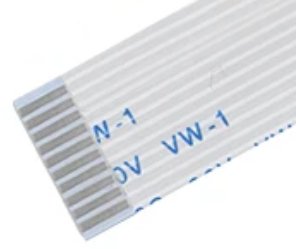
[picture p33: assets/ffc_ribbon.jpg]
    <td></td>
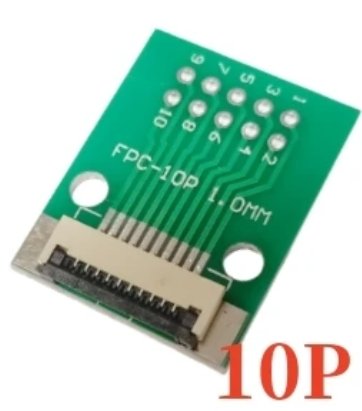
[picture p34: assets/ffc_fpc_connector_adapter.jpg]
    <td></td>
</tr>
</table>

# Top Screen

<table>
<tr>
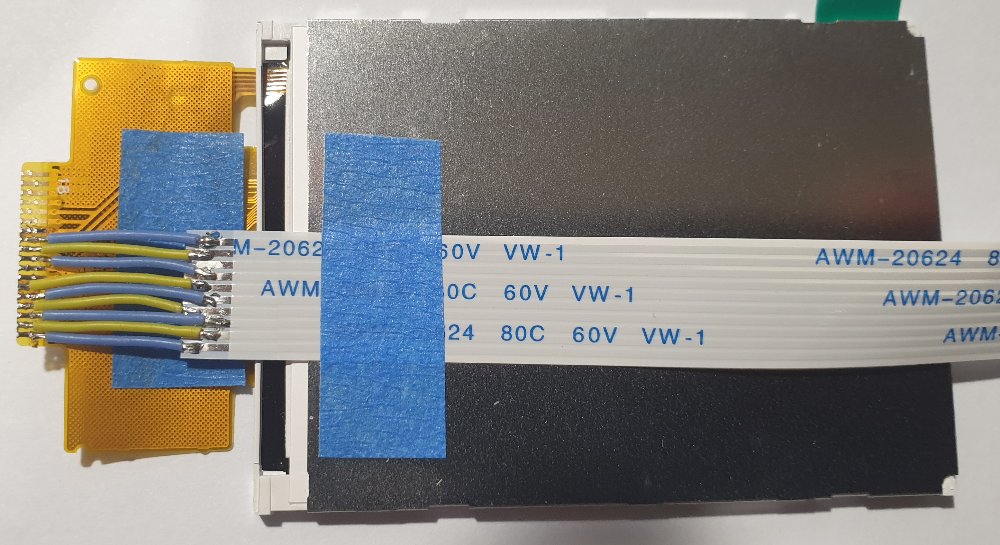
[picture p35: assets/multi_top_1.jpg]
    <td></td>
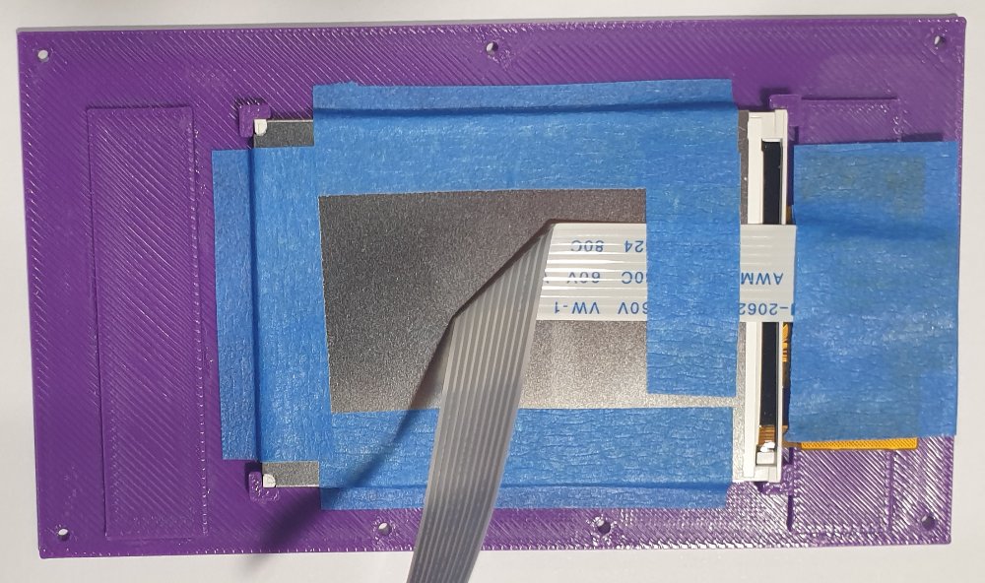
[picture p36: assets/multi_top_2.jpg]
    <td></td>
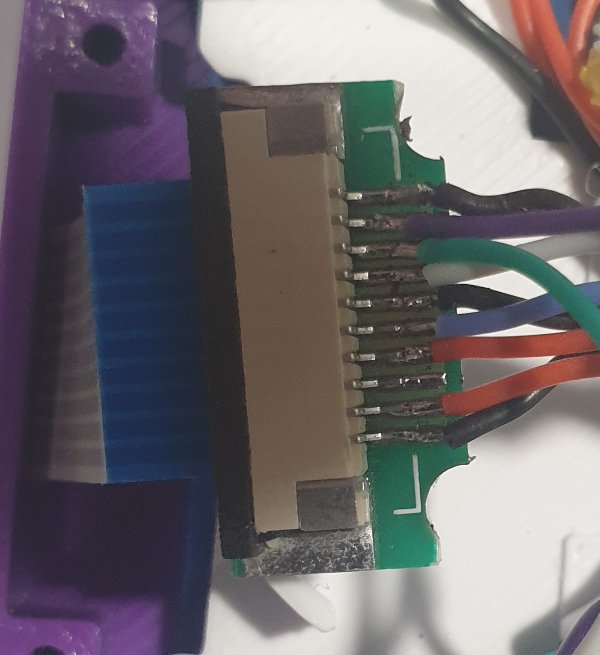
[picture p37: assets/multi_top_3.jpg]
    <td></td>
</tr>
</table>

Connect the display to a 10 pin ribbon cable using small wires.<br>
In the bottom screen section, trim size of ribbon cable connector adapter board so it will fit in space near the speaker.<br>
You might find it easier to skip ribbon cable adapter and solder directly to the ribbon cable.

# Power



## TP4056

A TP4056 module is used to charge the battery. These modules are designed for charging 18650 batteries at 1A.

To charge 10440 batteries, resistor R3 should be replaced with a 4.7kΩ resistor. This will charge the battery at approximately 250mA. To make it easier, after removing resistor R3, you can connect a wire to pin 2 of the main IC and mount the 4.7kΩ resistor on a perfboard with the other end connected to ground.

A mosfet (AO3401A) is used to disconnect the load from the battery while it is charging. This can be skipped if you remember to always turn off the device when it is charging. If you plan on using the mosfet, to make it easier you can connect a wire to pin 4 of the main IC and connect the other end to the schottky diode leading to the mosfet gate.

The TP4056 can only be mounted via the holes in the USB voltage pads. When you insert a screw into the pads it might break the connection between the top and bottom pads. If you plan to use these pads check to make sure the connection is not broken after you screw them in place.

## Battery Level Indicator

The battery voltage is sent to GPIO 16 for a battery level indicator. The ESP32-S3 ADC can measure voltages up to 3.1V so a voltage divider is used to drop the voltage to a suitable level.

With a few changes, the AO3401A mosfet can be setup to power the load from USB power while the battery is changing, however if you choose to do this you will also need to alter the voltage divider values to make sure the voltage at GPIO 16 does not exceed 3.1V.

## Jumper

A jumper has been placed between the ESP32 5v pin and the switch. This jumper should be open when connecting the ESP32 to USB for debugging. Failure to open the jumper will result in voltage from ESP32 making its way to the batteries if the switch is also turned on. You could skip the jumper installation, and always make sure the switch is off when debugging, but you will need the jumper installed and open if you want to debug the battery level indicator code.

## 3D Files

View 3D files: [Multi Screen Handheld 3D Files](../assets/3d_files/gandw_multi_screen_handheld/)

For a cleaner print and to save on supports "top case front" and "bottom case front" can be printed in parts.

If printing in parts to ensure proper alignment, glue the hinges in place while they are attached to the top case.

## Button Circuit Boards

The buttons need to be mounted on 2.54mm pitch perfboard. 

The alarm and ACL buttons need to be mounted slightly high on the board. Use the spacer (alarm_acl_button_spacer.stl) to mount them at the correct height.

The diagrams below show how to mount the buttons:

<table>
<tr>
    <td></td>
    <td></td>
</tr>
</table>

# Wiring

## LCD 1

- VCC:        ESP32 3.3v
- GND:        GND
- CS:         GND
- RESET:      GPIO 13
- DC:         GPIO 9
- MOSI        GPIO 11
- SCK:        GPIO 12
- LEDA:       ESP32 3.3v
- LEDK1:      GND  

## LCD 2

- VCC:        ESP32 3.3v
- GND:        GND
- CS:         GND
- RESET:      GPIO 39
- DC:         GPIO 38
- MOSI        GPIO 17
- SCK:        GPIO 18
- LEDA:       ESP32 3.3v
- LEDK1:      GND

## Max98357

- VIN:        ESP32 3.3v
- GND:        GND
- LRC (WS):   GPIO 4    
- BCLK:       GPIO 10
- DIN:        GPIO 6

## Buttons

- GAME A:       GPIO 14
- GAME B:       GPIO 5
- TIME:         GPIO 3
- LEFT:         GPIO 2
- RIGHT:        GPIO 1
- ALARM:        GPIO 7
- ACL:          GPIO 8

## Battery Level

- Battery +:   GPIO 16 (via voltage divider)

# Screen Resolution

The ESP32-S3-Zero does not have enough memory to display 2 screens at 320 x 240 resolution.

It does have enough memory to display 2 screens at 320 x 210 resolution.

This is closer to the aspect ratio of the original multi screen game and watch games and what i have used in this project.

This makes the total resolution 320 x 420.

# Roms

The roms must be in .gw format.

These can be created using LCD-Game-Shrinker.

https://github.com/bzhxx/LCD-Game-Shrinker

Below is a link to a guide describing how to use LCD-Game-Shrinker to generate the files.

https://gist.github.com/DNA64/16fed499d6bd4664b78b4c0a9638e4ef

Below is a list of the gw files required:

<table cellpadding="2" cellspacing="0">
<tr><td>Mame Rom</td><td>GW File</td></tr>
<tr><td>gnw_opanic</td><td>Game & Watch Oil Panic.gw</td></tr>
<tr><td>gnw_pinball</td><td>Game & Watch Pinball.gw</td></tr>
<tr><td>gnw_sbuster</td><td>Game & Watch Safe Buster.gw</td></tr>
</table>

## Additional Steps for Multi Screen Games

LCD Game Shrinker will convert multi screen games into one screen games in portrait mode, so we need to do some additional steps when generating the gw files.

Below are instructions to fix oil panic. All other multi screen games will be similar.

Make a copy of LCD-Game-Shrinker to use for multi screen games.

In the file shrink_it.py set: 

```
gw_height=420
```

In the custom directory, edit gnw_opanic.py

set rom.rotate to false

```
rom.rotate = False
```

Change rom.width_border_ratio from:

```
rom.width_border_ratio = 10/100
```

to:

```
rom.width_border_ratio = 0
```

## Black border between screens

If you run LCD Game Shrinker now there will be a black bar of about 10 pixels between the top and bottom screen.
The gw file will still work ok, but it is a good idea to remove it as it is wasting 10 pixels from the display.

To remove the black bar you need to:

- Extract the artwork zip file.
- Edit the default.lay file to remove the black bar.
- Zip the files again with the updated default.lay file.

In the default.lay file, find the view with the Backgrounds Only. (They usually have a height of 1669).

There is usually more than 1 background view. I am not sure which view LCD Game Shrinker uses so i was just updating all of them. They all use that same values so it is quick to update all of them at the same time.

```
<view name="Backgrounds Only">

<bounds x="32" y="33" width="1296" height="1669" />

    <element ref="Screen-Top">                    <bounds x="32" y="33" width="1296" height="817" /></element>
    <screen index="0" blend="multiply">            <bounds x="1" y="9" width="1349" height="899" /></screen>
    <element ref="Screen-Top">                    <bounds x="32" y="33" width="1296" height="817" /><color alpha="0.0" /></element>

    <element ref="Screen-Bottom">                <bounds x="32" y="885" width="1296" height="817" /></element>
    <screen index="1" blend="multiply">            <bounds x="-1" y="903" width="1371" height="878" /></screen>
    <element ref="Screen-Bottom">                <bounds x="32" y="885" width="1296" height="817" /><color alpha="0.00" /></element>
    <element ref="Balcony">                <bounds x="32" y="885" width="1296" height="817" /><color alpha="0.5" /></element>

</view>
```

New height: (Screen-Top + Screen-Bottom) 817 + 817 = 1634

Height difference: 1669 - 1634 = 35

Bounds height attribute is updated with the new height.

The height difference is removed from the y attribute of all the bottom screen elements.

```
<view name="Backgrounds Only">

<bounds x="32" y="33" width="1296" height="1634" />

    <element ref="Screen-Top">                    <bounds x="32" y="33" width="1296" height="817" /></element>
    <screen index="0" blend="multiply">            <bounds x="1" y="9" width="1349" height="899" /></screen>
    <element ref="Screen-Top">                    <bounds x="32" y="33" width="1296" height="817" /><color alpha="0.0" /></element>

    <element ref="Screen-Bottom">                <bounds x="32" y="850" width="1296" height="817" /></element>
    <screen index="1" blend="multiply">            <bounds x="-1" y="868" width="1371" height="878" /></screen>
    <element ref="Screen-Bottom">                <bounds x="32" y="850" width="1296" height="817" /><color alpha="0.00" /></element>
    <element ref="Balcony">                <bounds x="32" y="850" width="1296" height="817" /><color alpha="0.5" /></element>

</view>
```

# Building

Install the ESP-IDF framework. The version I used was v6.0.1.
https://docs.espressif.com/projects/esp-idf/en/stable/esp32s3/get-started/index.html

Make sure you can build the hello_world example project.

Download the code from this repo.

Use LCD-Game-Shrinker to generate a game files (see above) and place the gw files in the /gandw_handheld/main/ directory.

Go back to /gandw_handheld/ directory and open the terminal or cmd window in this directory.

## Linux

These instructions are for linux. If you are using windows follow the same steps you did when building the hello_world example project.

Run the export.sh script or get_idf if you set it up.

Export script should be similar to: 

```
. $HOME/esp/esp-idf/export.sh
```

Build: 

```
idf.py build
```

Then: 

```
idf.py -DDISPLAY=ili9341 -DMODEL=multi_screen_2_button -p /dev/ttyACM0 flash
```

or

```
idf.py -DDISPLAY=st7789 -DMODEL=multi_screen_2_button -p /dev/ttyACM0 flash
```

You can also monitor by adding monitor at the end: 

```
idf.py -DMODEL=multi_screen_2_button -p /dev/ttyACM0 flash monitor 
```

Press Ctrl and ] to exit monitor.

If you are getting errors try a fullclean before building: 

```
idf.py fullclean
```

# LCD Display

## Orientation

In the display.c source file, there are 2 commands that you can use to change the screen orientation.

- esp_lcd_panel_swap_xy
- esp_lcd_panel_mirror

## Pixel Data

All the lcd panels i used required the pixel data to be byte swapped for the image to be displayed correctly.

I have swapped the byte order for the background and segment pixel data in lcd game emulator.

If the image displayed on your screen looks incorrect (wrong colours) you can change the byte swap setting.

In the file: /components/lcd_game_emulator/src/gw_sys/gw_system.h, set BYTE_SWAP to 0.

```
#define BYTE_SWAP 0
```

# Acknowledgements

## LCD-Game-Emulator

https://github.com/bzhxx/lcd-game-emulator

## Retro-Go

https://github.com/ducalex/retro-go

The LCD-Game-Emulator version used by the project was copied from Retro-Go because it contains additional code to handle the loading of the gw files.

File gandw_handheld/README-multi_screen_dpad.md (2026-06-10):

# Multi Screen D-pad Handheld

# Disclaimer:

This project is a work in progress.

I assume no responsibility or liability for any errors, omissions, or outcomes resulting from the use of the information provided within this project.

You are strongly advised to conduct your own thorough research and ensure you have a comprehensive understanding of best practices for the safe charging and handling of Li-ion batteries. Improper handling can lead to serious risks, including but not limited to fire, explosion, or personal injury.

Use the information provided in this project at your own risk.

<table>
<tr>
    <td align="center">Front</td>
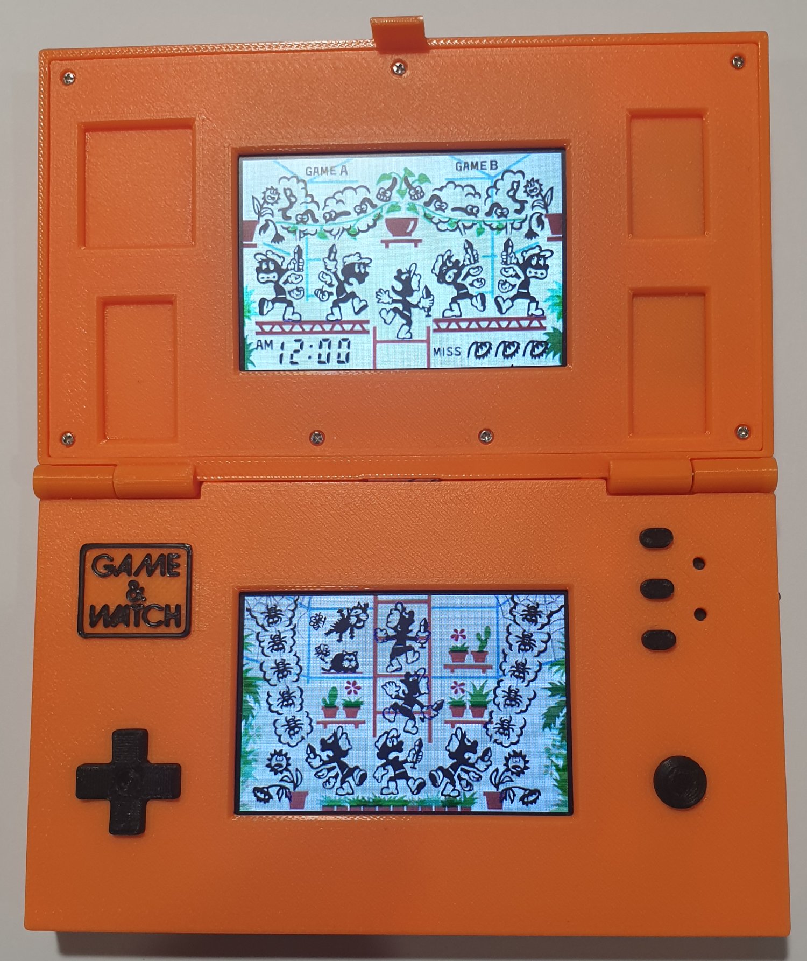
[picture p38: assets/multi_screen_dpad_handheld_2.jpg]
    <td align="center"></td>
</tr>
<tr>
    <td align="center">Front</td>
    <td align="center">Front</td>
</tr>
<tr><td colspan="2">Internal</td></tr>
</table>

# Features

Plays 6  multi screen dpad game and watch games.<br>
Use the left and right buttons in the menu to select a game, then press jump to start the game.<br>
You can return to the menu by pressing the left and jump buttons for a few seconds.

## Volume Adjustment

Volume adjustment with on screen display.<br>
Volume down: Time and Left buttons.<br>
Volume up: Time and Right buttons.<br>
Remembers volume level on power up.

## Power

Two 10440 batteries, USB-C charging and on/off switch.

## Battery Level Indicator

Battery level is displayed on power up.

# Components

- ESP32-S3-Zero
- Display: 2 x 2.4 inch SPI panel 240x320 LCD with ILI9341 or ST7789V driver
  (No board - LCD only, No Touch. AliExpress seller: XunMing Store)
- Audio: Max98357 I2S Amp
- Speaker: 20mm
- USB-C TP4056 Battery Charger Module 
- 2 x 10440 Li-ion batteries
- Mini Push Buttons 4.5mm x 4.5mm x 3.8mm
- 3mm SS12d00 mini slide switch.
- AO3401A mosfet
- 1N5817 schottky diode
- 10cm FFC Flexible Flat Ribbon Cable - 1.0mm Pitch 10 Pin.
- FFC FPC connector adapter board. 10P - 1mm pitch.
- Resistors: 2 x 4.7K, 10K and 100K
- Screws M2 - 4mm, 6mm and 8mm long.
- Screws to mount the TP4056 module. 2 x M1.5
- Screws to mount the top display. 7 x M1.5 3mm long.
- Hinge screws: M2 x 20mm long

<table>
<tr>
    <td></td>
    <td></td>
    <td></td>    
    <td></td>
    <td></td>
</tr>
</table>

<table>
<tr>
    <td></td>
    <td></td>
    <td></td>
    <td></td>
    <td></td>
</tr>
</table>

# Top Screen

<table>
<tr>
    <td></td>
    <td></td>
    <td></td>
</tr>
</table>

Connect the display to a 10 pin ribbon cable using small wires.<br>
In the bottom screen section, trim size of ribbon cable connector adapter board so it will fit in the case.<br>
You might find it easier to skip ribbon cable adapter and solder directly to the ribbon cable.

# Power



## TP4056

A TP4056 module is used to charge the battery. These modules are designed for charging 18650 batteries at 1A.

To charge 10440 batteries, resistor R3 should be replaced with a 4.7kΩ resistor. This will charge the battery at approximately 250mA. To make it easier, after removing resistor R3, you can connect a wire to pin 2 of the main IC and mount the 4.7kΩ resistor on a perfboard with the other end connected to ground.

A mosfet (AO3401A) is used to disconnect the load from the battery while it is charging. This can be skipped if you remember to always turn off the device when it is charging. If you plan on using the mosfet, to make it easier you can connect a wire to pin 4 of the main IC and connect the other end to the schottky diode leading to the mosfet gate.

The TP4056 can only be mounted via the holes in the USB voltage pads. When you insert a screw into the pads it might break the connection between the top and bottom pads. If you plan to use these pads check to make sure the connection is not broken after you screw them in place.

## Battery Level Indicator

The battery voltage is sent to GPIO 16 for a battery level indicator. The ESP32-S3 ADC can measure voltages up to 3.1V so a voltage divider is used to drop the voltage to a suitable level.

With a few changes, the AO3401A mosfet can be setup to power the load from USB power while the battery is changing, however if you choose to do this you will also need to alter the voltage divider values to make sure the voltage at GPIO 16 does not exceed 3.1V.

## Jumper

A jumper has been placed between the ESP32 5v pin and the switch. This jumper should be open when connecting the ESP32 to USB for debugging. Failure to open the jumper will result in voltage from ESP32 making its way to the batteries if the switch is also turned on. You could skip the jumper installation, and always make sure the switch is off when debugging, but you will need the jumper installed and open if you want to debug the battery level indicator code.

## 3D Files

View 3D files: [Multi Screen D-pad Handheld 3D Files](../assets/3d_files/gandw_multi_screen_dpad_handheld/)

For a cleaner print and to save on supports "top case front" and "bottom case front" can be printed in parts.

If printing in parts to ensure proper alignment, glue the hinges in place while they are attached to the top case.

## Button Circuit Boards

The buttons need to be mounted on 2.54mm pitch perfboard. 

The alarm and ACL buttons need to be mounted slightly high on the board. Use the spacer (alarm_acl_button_spacer.stl) to mount them at the correct height.

The diagrams below show how to mount the buttons:

<table>
<tr>
    <td></td>
    <td></td>
    <td></td>
</tr>
</table>

# Wiring

## LCD 1

- VCC:        ESP32 3.3v
- GND:        GND
- CS:         GND
- RESET:      GPIO 13
- DC:         GPIO 9
- MOSI        GPIO 11
- SCK:        GPIO 12
- LEDA:       ESP32 3.3v
- LEDK1:      GND  

## LCD 2

- VCC:        ESP32 3.3v
- GND:        GND
- CS:         GND
- RESET:      GPIO 39
- DC:         GPIO 38
- MOSI        GPIO 17
- SCK:        GPIO 18
- LEDA:       ESP32 3.3v
- LEDK1:      GND

## Max98357

- VIN:        ESP32 3.3v
- GND:        GND
- LRC (WS):   GPIO 4    
- BCLK:       GPIO 10
- DIN:        GPIO 6

## Buttons

- GAME A:       GPIO 14
- GAME B:       GPIO 5
- TIME:         GPIO 3
- LEFT:         GPIO 41
- RIGHT:        GPIO 40
- UP:           GPIO 42
- DOWN:         GPIO 2
- JUMP:         GPIO 1
- ALARM:        GPIO 7
- ACL:          GPIO 8

## Battery Level

- Battery +:   GPIO 16 (via voltage divider)

# Screen Resolution

The ESP32-S3-Zero does not have enough memory to display 2 screens at 320 x 240 resolution.

It does have enough memory to display 2 screens at 320 x 210 resolution.

This is closer to the aspect ratio of the original multi screen game and watch games and what i have used in this project.

This makes the total resolution 320 x 420.

# Roms

The roms must be in .gw format.

These can be created using LCD-Game-Shrinker.

https://github.com/bzhxx/LCD-Game-Shrinker

Below is a link to a guide describing how to use LCD-Game-Shrinker to generate the files.

https://gist.github.com/DNA64/16fed499d6bd4664b78b4c0a9638e4ef

Below is a list of the gw files required:

<table cellpadding="2" cellspacing="0">
<tr><td>Mame Rom</td><td>GW File</td></tr>
<tr><td>gnw_dkong</td><td>Game & Watch Donkey Kong.gw</td></tr>
<tr><td>gnw_ghouse</td><td>Game & Watch Green House.gw</td></tr>
<tr><td>gnw_dkong2</td><td>Game & Watch Donkey Kong II.gw</td></tr>
<tr><td>gnw_bsweep</td><td>Game & Watch Bomb Sweeper.gw</td></tr>
<tr><td>gnw_gcliff</td><td>Game & Watch Gold Cliff.gw</td></tr>
<tr><td>gnw_zelda</td><td>Game & Watch Zelda.gw</td></tr>
</table>

## Additional Steps for Multi Screen Games

LCD Game Shrinker will convert multi screen games into one screen games in portrait mode, so we need to do some additional steps when generating the gw files.

Below are instructions to fix oil panic. All other multi screen games will be similar.

Make a copy of LCD-Game-Shrinker to use for multi screen games.

In the file shrink_it.py set: 

```
gw_height=420
```

In the custom directory, edit gnw_opanic.py

set rom.rotate to false

```
rom.rotate = False
```

Change rom.width_border_ratio from:

```
rom.width_border_ratio = 10/100
```

to:

```
rom.width_border_ratio = 0
```

## Black border between screens

If you run LCD Game Shrinker now there will be a black bar of about 10 pixels between the top and bottom screen.
The gw file will still work ok, but it is a good idea to remove it as it is wasting 10 pixels from the display.

To remove the black bar you need to:

- Extract the artwork zip file.
- Edit the default.lay file to remove the black bar.
- Zip the files again with the updated default.lay file.

In the default.lay file, find the view with the Backgrounds Only. (They usually have a height of 1669).

There is usually more than 1 background view. I am not sure which view LCD Game Shrinker uses so i was just updating all of them. They all use that same values so it is quick to update all of them at the same time.

```
<view name="Backgrounds Only">

<bounds x="32" y="33" width="1296" height="1669" />

    <element ref="Screen-Top">                    <bounds x="32" y="33" width="1296" height="817" /></element>
    <screen index="0" blend="multiply">            <bounds x="1" y="9" width="1349" height="899" /></screen>
    <element ref="Screen-Top">                    <bounds x="32" y="33" width="1296" height="817" /><color alpha="0.0" /></element>

    <element ref="Screen-Bottom">                <bounds x="32" y="885" width="1296" height="817" /></element>
    <screen index="1" blend="multiply">            <bounds x="-1" y="903" width="1371" height="878" /></screen>
    <element ref="Screen-Bottom">                <bounds x="32" y="885" width="1296" height="817" /><color alpha="0.00" /></element>
    <element ref="Balcony">                <bounds x="32" y="885" width="1296" height="817" /><color alpha="0.5" /></element>

</view>
```

New height: (Screen-Top + Screen-Bottom) 817 + 817 = 1634

Height difference: 1669 - 1634 = 35

Bounds height attribute is updated with the new height.

The height difference is removed from the y attribute of all the bottom screen elements.

```
<view name="Backgrounds Only">

<bounds x="32" y="33" width="1296" height="1634" />

    <element ref="Screen-Top">                    <bounds x="32" y="33" width="1296" height="817" /></element>
    <screen index="0" blend="multiply">            <bounds x="1" y="9" width="1349" height="899" /></screen>
    <element ref="Screen-Top">                    <bounds x="32" y="33" width="1296" height="817" /><color alpha="0.0" /></element>

    <element ref="Screen-Bottom">                <bounds x="32" y="850" width="1296" height="817" /></element>
    <screen index="1" blend="multiply">            <bounds x="-1" y="868" width="1371" height="878" /></screen>
    <element ref="Screen-Bottom">                <bounds x="32" y="850" width="1296" height="817" /><color alpha="0.00" /></element>
    <element ref="Balcony">                <bounds x="32" y="850" width="1296" height="817" /><color alpha="0.5" /></element>

</view>
```

# Building

Install the ESP-IDF framework. The version I used was v6.0.1.
https://docs.espressif.com/projects/esp-idf/en/stable/esp32s3/get-started/index.html

Make sure you can build the hello_world example project.

Download the code from this repo.

Use LCD-Game-Shrinker to generate a game files (see above) and place the gw files in the /gandw_handheld/main/ directory.

Go back to /gandw_handheld/ directory and open the terminal or cmd window in this directory.

## Linux

These instructions are for linux. If you are using windows follow the same steps you did when building the hello_world example project.

Run the export.sh script or get_idf if you set it up.

Export script should be similar to: 

```
. $HOME/esp/esp-idf/export.sh
```

Build: 

```
idf.py build
```

Then: 

```
idf.py -DDISPLAY=ili9341 -DMODEL=multi_screen_dpad -p /dev/ttyACM0 flash
```

or

```
idf.py -DDISPLAY=st7789 -DMODEL=multi_screen_dpad -p /dev/ttyACM0 flash
```

You can also monitor by adding monitor at the end: 

```
idf.py -DMODEL=multi_screen_dpad -p /dev/ttyACM0 flash monitor 
```

Press Ctrl and ] to exit monitor.

If you are getting errors try a fullclean before building: 

```
idf.py fullclean
```

# LCD Display

## Orientation

In the display.c source file, there are 2 commands that you can use to change the screen orientation.

- esp_lcd_panel_swap_xy
- esp_lcd_panel_mirror

## Pixel Data

All the lcd panels i used required the pixel data to be byte swapped for the image to be displayed correctly.

I have swapped the byte order for the background and segment pixel data in lcd game emulator.

If the image displayed on your screen looks incorrect (wrong colours) you can change the byte swap setting.

In the file: /components/lcd_game_emulator/src/gw_sys/gw_system.h, set BYTE_SWAP to 0.

```
#define BYTE_SWAP 0
```

# Acknowledgements

## LCD-Game-Emulator

https://github.com/bzhxx/lcd-game-emulator

## Retro-Go

https://github.com/ducalex/retro-go

The LCD-Game-Emulator version used by the project was copied from Retro-Go because it contains additional code to handle the loading of the gw files.

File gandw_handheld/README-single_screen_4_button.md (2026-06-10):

# Single Screen 4 Button Handheld

# Disclaimer: 

This project is a work in progress.

I assume no responsibility or liability for any errors, omissions, or outcomes resulting from the use of the information provided within this project.

You are strongly advised to conduct your own thorough research and ensure you have a comprehensive understanding of best practices for the safe charging and handling of Li-ion batteries. Improper handling can lead to serious risks, including but not limited to fire, explosion, or personal injury.

Use the information provided in this project at your own risk.

<table>
<tr><td colspan="2">4 Button Handheld</td></tr>
<tr><td colspan="2">4 Button Handheld</td></tr>
<tr><td colspan="2">4 Button Handheld</td></tr>
<tr>
    <td>4 Button Handheld</td>
    <td>4 Button Handheld</td>
</tr>
<tr>
    <td>4 Button Handheld</td>
    <td>4 Button Handheld</td>
</tr>
</table>

# Features

## 22 Games
Plays 22 two and four button game and watch games.<br>
Use the left and right buttons in the menu to select a game, then press Game A to start the game.<br>
You can return to the menu by pressing the left and right buttons for a few seconds.

## Volume Adjustment
Volume adjustment with on screen display.<br>
Volume down: Time and Left buttons.<br>
Volume up: Time and Right buttons.<br>
Remembers volume level on power up.

## Power
Two 10440 batteries, USB-C charging and on/off switch.

## Battery Level Indicator
Battery level is displayed on power up.

# Components
- ESP32-S3-Zero
- Display: 2.4 inch SPI panel 240x320 LCD with ILI9341 or ST7789V driver
  (No board - LCD only, No Touch. AliExpress seller: XunMing Store)
- Audio: Max98357 I2S Amp
- Speaker: 20mm
- USB-C TP4056 Battery Charger Module 
- 2 x 10440 Li-ion batteries
- Mini Push Buttons 4.5mm x 4.5mm x 3.8mm
- 3mm SS12d00 mini slide switch.
- AO3401A mosfet
- 1N5817 schottky diode
- Resistors: 2 x 4.7K, 10K and 100K
- Screws M2 - 4mm, 6mm and 8mm long.
- Screws to mount the TP4056 module. 2 x M1.5

<table>
<tr>
    <td></td>
    <td></td>
    <td></td>    
    <td></td>
</tr>
</table>

<table>
<tr>
    <td></td>
    <td></td>
    <td></td>
    <td></td>
</tr>
</table>

# Power



## TP4056

A TP4056 module is used to charge the battery. These modules are designed for charging 18650 batteries at 1A.

To charge 10440 batteries, resistor R3 should be replaced with a 4.7kΩ resistor. This will charge the battery at approximately 250mA. To make it easier, after removing resistor R3, you can connect a wire to pin 2 of the main IC and mount the 4.7kΩ resistor on a perfboard with the other end connected to ground.

A mosfet (AO3401A) is used to disconnect the load from the battery while it is charging. This can be skipped if you remember to always turn off the device when it is charging. If you plan on using the mosfet, to make it easier you can connect a wire to pin 4 of the main IC and connect the other end to the schottky diode leading to the mosfet gate.

The TP4056 can only be mounted via the holes in the USB voltage pads. When you insert a screw into the pads it might break the connection between the top and bottom pads. If you plan to use these pads check to make sure the connection is not broken after you screw them in place.

## Battery Level Indicator

The battery voltage is sent to GPIO 16 for a battery level indicator. The ESP32-S3 ADC can measure voltages up to 3.1V so a voltage divider is used to drop the voltage to a suitable level.

With a few changes, the AO3401A mosfet can be setup to power the load from USB power while the battery is changing, however if you choose to do this you will also need to alter the voltage divider values to make sure the voltage at GPIO 16 does not exceed 3.1V.

## Jumper

A jumper has been placed between the ESP32 5v pin and the switch. This jumper should be open when connecting the ESP32 to USB for debugging. Failure to open the jumper will result in voltage from ESP32 making its way to the batteries if the switch is also turned on. You could skip the jumper installation, and always make sure the switch is off when debugging, but you will need the jumper installed and open if you want to debug the battery level indicator code.

## 3D Files

View 3D files: [Single Screen 4 Button Handheld 3D Files](../assets/3d_files/gandw_single_screen_4button_handheld/)

## Button Circuit Boards

The buttons need to be mounted on 2.54mm pitch perfboard. 

The alarm and ACL buttons need to be mounted slightly high on the board. Use the spacer (alarm_acl_button_spacer.stl) to mount them at the correct height.

The diagrams below show how to mount the buttons:

<table>
<tr>
    <td></td>
    <td></td>
</tr>
</table>

# Wiring

## LCD
- VCC:        ESP32 3.3v
- GND:        GND
- CS:         GND
- RESET:      GPIO 13
- DC:         GPIO 9
- MOSI        GPIO 11
- SCK:        GPIO 12
- LEDA:       ESP32 3.3v
- LEDK1:      GND  

## Max98357
- VIN:        ESP32 3.3v
- GND:        GND
- LRC (WS):   GPIO 4    
- BCLK:       GPIO 10
- DIN:        GPIO 6

## Buttons
- GAME A:       GPIO 14
- GAME B:       GPIO 5
- TIME:         GPIO 3
- LEFT DOWN:    GPIO 2
- RIGHT DOWN:   GPIO 1
- LEFT UP:      GPIO 17
- RIGHT UP:     GPIO 18
- ALARM:        GPIO 7
- ACL:          GPIO 8

## Battery Level
- Battery +:   GPIO 16 (via voltage divider)

# Roms

The roms must be in .gw format.

These can be created using LCD-Game-Shrinker.

https://github.com/bzhxx/LCD-Game-Shrinker

Below is a link to a guide describing how to use LCD-Game-Shrinker to generate the files.

https://gist.github.com/DNA64/16fed499d6bd4664b78b4c0a9638e4ef

Below is a list of the gw files required:

<table cellpadding="2" cellspacing="0">
<tr><td>Mame Rom</td><td>GW File</td></tr>
<tr><td>gnw_pchute</td><td>Game & Watch Parachute.gw</td></tr>
<tr><td>gnw_octopus</td><td>Game & Watch Octopus.gw</td></tr>
<tr><td>gnw_fire</td><td>Game & Watch Fire (Wide Screen).gw</td></tr>
<tr><td>gnw_chef</td><td>Game & Watch Chef.gw</td></tr>
<tr><td>gnw_popeye</td><td>Game & Watch Popeye (Wide Screen).gw</td></tr>
<tr><td>gnw_tbridge</td><td>Game & Watch Turtle Bridge.gw</td></tr>
<tr><td>gnw_vermin</td><td>Game & Watch Vermin.gw</td></tr>
<tr><td>gnw_ball</td><td>Game & Watch Ball.gw</td></tr>
<tr><td>gnw_fires</td><td>Game & Watch Fire (Silver).gw</td></tr>
<tr><td>gnw_helmet</td><td>Game & Watch Helmet (CN-17 version).gw</td></tr>
<tr><td>gnw_mariotj</td><td>Game & Watch Mario The Juggler.gw</td></tr>
<tr><td>gnw_tfish</td><td>Game & Watch Tropical Fish.gw</td></tr>
<tr><td>gnw_egg</td><td>Game & Watch Egg.gw</td></tr>
<tr><td>gnw_fireatk</td><td>Game & Watch Fire Attack.gw</td></tr>
<tr><td>gnw_flagman</td><td>Game & Watch Flagman.gw</td></tr>
<tr><td>gnw_judge</td><td>Game & Watch Judge (green version).gw</td></tr>
<tr><td>gnw_lion</td><td>Game & Watch Lion.gw</td></tr>
<tr><td>gnw_manhole</td><td>Game & Watch Manhole (New Wide Screen).gw</td></tr>
<tr><td>gnw_manholeg</td><td>Game & Watch Manhole (Gold).gw</td></tr>
<tr><td>gnw_mariocm</td><td>Game & Watch Mario's Cement Factory (New Wide Screen).gw</td></tr>
<tr><td>gnw_mmouse</td><td>Game & Watch Mickey Mouse (Wide Screen).gw</td></tr>
<tr><td>gnw_stennis</td><td>Game & Watch Snoopy Tennis.gw</td></tr>
</table>

# Building
Install the ESP-IDF framework. The version I used was v6.0.1.
https://docs.espressif.com/projects/esp-idf/en/stable/esp32s3/get-started/index.html

Make sure you can build the hello_world example project.

Download the code from this repo.

Use LCD-Game-Shrinker to generate a game files (see above) and place the gw files in the /gandw_handheld/main/ directory.

Go back to /gandw_handheld/ directory and open the terminal or cmd window in this directory.

## Linux

These instructions are for linux. If you are using windows follow the same steps you did when building the hello_world example project.

Run the export.sh script or get_idf if you set it up.

Export script should be similar to: 

```
. $HOME/esp/esp-idf/export.sh
```

Build: 

```
idf.py build
```

Then: 

```
idf.py -DDISPLAY=ili9341 -DMODEL=single_screen_4_button -p /dev/ttyACM0 flash
```

or

```
idf.py -DDISPLAY=st7789 -DMODEL=single_screen_4_button -p /dev/ttyACM0 flash
```

You can also monitor by adding monitor at the end: 

```
idf.py -DMODEL=single_screen_4_button -p /dev/ttyACM0 flash monitor 
```

Press Ctrl and ] to exit monitor.

If you are getting errors try a fullclean before building: 

```
idf.py fullclean
```

# LCD Display

## Orientation

In the display.c source file, there are 2 commands that you can use to change the screen orientation.

- esp_lcd_panel_swap_xy
- esp_lcd_panel_mirror

## Pixel Data

All the lcd panels i used required the pixel data to be byte swapped for the image to be displayed correctly.

I have swapped the byte order for the background and segment pixel data in lcd game emulator.

If the image displayed on your screen looks incorrect (wrong colours) you can change the byte swap setting.

In the file: /components/lcd_game_emulator/src/gw_sys/gw_system.h, set BYTE_SWAP to 0.

```
#define BYTE_SWAP 0
```

# Acknowledgements

## LCD-Game-Emulator
https://github.com/bzhxx/lcd-game-emulator

## Retro-Go
https://github.com/ducalex/retro-go

The LCD-Game-Emulator version used by the project was copied from Retro-Go because it contains additional code to handle the loading of the gw files.

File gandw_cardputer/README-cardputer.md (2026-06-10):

# Game and Watch for the Cardputer

Tested with Cardputer v1.1 and Cardputer Adv.

<table>
<tr>
    <td align="center">Cardputer</td>
</tr>
<tr>
    <td align="center">Cardputer</td>
</tr>
<tr>
    <td align="center">Cardputer</td>
</tr>
<tr>
    <td align="center">Cardputer</td>
</tr>
</table>

# Games

Supports 26 single screen Game and Watch games.<br>
Use the left and right arrow keys in the menu to select a game, then press Ok to start the game.<br>
You can return to the menu by pressing and holding the backspace key or pressing the cardputers reset button.

# Buttons

## Speaker Volume
<table>
<tr>
    <td>Up</td><td>;</td>
</tr>
<tr>
    <td>Down</td><td>.</td>
</tr>
</table>

## Main Buttons

<table>
<tr>
    <td>Game A</td><td>1</td>
</tr>
<tr>
    <td>Game B</td><td>2</td>
</tr>
<tr>
    <td>Time</td><td>3</td>
</tr>
<tr>
    <td>Alarm</td><td>4</td>
</tr>
<tr>
    <td>ACL</td><td>5</td>
</tr>
</table>

## 2 Button Games

<table>
<tr>
    <td>Left</td><td>ctrl</td>
</tr>
<tr>
    <td>Right</td><td>space</td>
</tr>
</table>

## 4 Button Games

<table>
<tr>
    <td>Left Up</td><td>fn</td>
</tr>
<tr>
    <td>Left Down</td><td>ctrl</td>
</tr>
<tr>
    <td>Right Up</td><td>enter</td>
</tr>
<tr>
    <td>Right Down</td><td>space</td>
</tr>
</table>

Mario's Cement Factory

<table>
<tr>
    <td>Left</td><td>ctrl</td>
</tr>
<tr>
    <td>Right</td><td>opt</td>
</tr>
<tr>
    <td>Open</td><td>space</td>
</tr>
</table>

## Directional Button Games

<table>
<tr>
    <td>Left</td><td>ctrl</td>
</tr>
<tr>
    <td>Right</td><td>alt</td>
</tr>
<tr>
    <td>Up</td><td>Aa</td>
</tr>
<tr>
    <td>Down</td><td>opt</td>
</tr>
<tr>
    <td>Button</td><td>space</td>
</tr>
</table>

# Roms
The roms must be in .gw format. 

These need to be created using LCD-Game-Shrinker from the MAME rom and artwork files.

You can download LCD-Game-Shrinker from here:

https://github.com/bzhxx/LCD-Game-Shrinker

You need to set the resoultion in LCD-Game-Shrinker to match the CardPuter's display.

In the file shrink_it.py change: 
```
gw_width=320
gw_height=240
```

to

```
gw_width=240
gw_height=135
```

Below is a list of the gw files required:

<table cellpadding="2" cellspacing="0">
<tr><td>Mame Rom</td><td>GW File</td></tr>
<tr><td>gnw_pchute</td><td>Game & Watch Parachute.gw</td></tr>
<tr><td>gnw_octopus</td><td>Game & Watch Octopus.gw</td></tr>
<tr><td>gnw_fire</td><td>Game & Watch Fire (Wide Screen).gw</td></tr>
<tr><td>gnw_chef</td><td>Game & Watch Chef.gw</td></tr>
<tr><td>gnw_popeye</td><td>Game & Watch Popeye (Wide Screen).gw</td></tr>
<tr><td>gnw_tbridge</td><td>Game & Watch Turtle Bridge.gw</td></tr>
<tr><td>gnw_vermin</td><td>Game & Watch Vermin.gw</td></tr>
<tr><td>gnw_ball</td><td>Game & Watch Ball.gw</td></tr>
<tr><td>gnw_fires</td><td>Game & Watch Fire (Silver).gw</td></tr>
<tr><td>gnw_helmet</td><td>Game & Watch Helmet (CN-17 version).gw</td></tr>
<tr><td>gnw_mariotj</td><td>Game & Watch Mario The Juggler.gw</td></tr>
<tr><td>gnw_tfish</td><td>Game & Watch Tropical Fish.gw</td></tr>
<tr><td>gnw_egg</td><td>Game & Watch Egg.gw</td></tr>
<tr><td>gnw_fireatk</td><td>Game & Watch Fire Attack.gw</td></tr>
<tr><td>gnw_flagman</td><td>Game & Watch Flagman.gw</td></tr>
<tr><td>gnw_judge</td><td>Game & Watch Judge (green version).gw</td></tr>
<tr><td>gnw_lion</td><td>Game & Watch Lion.gw</td></tr>
<tr><td>gnw_manhole</td><td>Game & Watch Manhole (New Wide Screen).gw</td></tr>
<tr><td>gnw_manholeg</td><td>Game & Watch Manhole (Gold).gw</td></tr>
<tr><td>gnw_mariocm</td><td>Game & Watch Mario's Cement Factory (New Wide Screen).gw</td></tr>
<tr><td>gnw_mmouse</td><td>Game & Watch Mickey Mouse (Wide Screen).gw</td></tr>
<tr><td>gnw_stennis</td><td>Game & Watch Snoopy Tennis.gw</td></tr>
<tr><td>gnw_dkjr</td><td>Game & Watch Donkey Kong Jr. (New Wide Screen).gw</td></tr>
<tr><td>gnw_bfightn</td><td>Game & Watch Balloon Fight (New Wide Screen).gw</td></tr>
<tr><td>gnw_climbern</td><td>Game & Watch Climber (New Wide Screen).gw</td></tr>
<tr><td>gnw_smbn</td><td>Game & Watch Super Mario Bros. (New Wide Screen).gw</td></tr>
</table>

Below is a link to a guide describing how to use LCD-Game-Shrinker to generate the files.

https://gist.github.com/DNA64/16fed499d6bd4664b78b4c0a9638e4ef

# Building
Install the ESP-IDF framework. The version I used was v6.0.1.
https://docs.espressif.com/projects/esp-idf/en/stable/esp32s3/get-started/index.html

Make sure you can build the hello_world example project.

Download the code from this repo.

Use LCD-Game-Shrinker to generate the game files (see above) and place the gw files in the /gandw_cardputer/main/ directory.

Go back to /gandw_cardputer/ directory and open the terminal or cmd window in this directory.

## Linux

These instructions are for linux. If you are using windows follow the same steps you did when building the hello_world example project.

Run the export.sh script or get_idf if you set it up.

Export script should be similar to: 

```
. $HOME/esp/esp-idf/export.sh
```

Build: 

```
idf.py build
```

Then: 

```
idf.py -DMODEL=cardputer -p /dev/ttyACM0 flash
```

You can also monitor by adding monitor at the end: 

```
idf.py -DMODEL=cardputer -p /dev/ttyACM0 flash monitor 
```

Press Ctrl and ] to exit monitor.

If you are getting errors try a fullclean before building: 

```
idf.py fullclean
```

# Acknowledgements

## LCD-Game-Emulator
https://github.com/bzhxx/lcd-game-emulator

## Retro-Go
https://github.com/ducalex/retro-go

The LCD-Game-Emulator version used by the project was copied from Retro-Go because it contains additional code to handle the loading of the gw files.

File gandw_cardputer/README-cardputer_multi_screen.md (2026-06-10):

# Game and Watch Multi Screen for the Cardputer Adv

Play Multi Screen Game and Watch games using an external display on the cardputer adv.<br>

The Cardputer does not have any PSRAM and only has just enough memory to display Game and Watch multi‑screen games on two 240x135 displays.<br>

<table>
<tr>
    <td align="center">Cardputer</td>
</tr>
<tr>
    <td align="center">Cardputer</td>
</tr>
<tr>
    <td align="center">Cardputer</td>
</tr>
<tr>
    <td align="center">Cardputer</td>
</tr>
</table>

# Games

Supports 12 multi screen Game and Watch games.<br>
Use the left and right arrow keys in the menu to select a game, then press Ok to start the game.<br>
You can return to the menu by pressing and holding the backspace key or pressing the cardputers reset button.

# Display

I used a 2 inch ST7789V 320x240 SPI Interface Display Module.

ST7789V

## Wiring
- VCC:        5v out
- GND:        GND
- CS:         GPIO 5
- DC:         GPIO 15
- RST:        GPIO 13
- SDA/MOSI:   GPIO 14
- SCK/SCL:    GPIO 39

It should be ok to use any ST7789V panel that is at least 240x135.

If your panel is not 320x240 update /gandw_cardputer/main/display.h with the details.

```
#define DISPLAY2_WIDTH 320
#define DISPLAY2_HEIGHT 240
```

You can adjust the position of the rendered content in /gandw_cardputer/main/display.c

```
// position top display here
esp_lcd_panel_set_gap(display_2_handle, 40, 53);
```

# Buttons

## Speaker Volume
<table>
<tr>
    <td>Up</td><td>;</td>
</tr>
<tr>
    <td>Down</td><td>.</td>
</tr>
</table>

## Main Buttons

<table>
<tr>
    <td>Game A</td><td>1</td>
</tr>
<tr>
    <td>Game B</td><td>2</td>
</tr>
<tr>
    <td>Time</td><td>3</td>
</tr>
<tr>
    <td>Alarm</td><td>4</td>
</tr>
<tr>
    <td>ACL</td><td>5</td>
</tr>
</table>

## 2 Button Games

<table>
<tr>
    <td>Left</td><td>ctrl</td>
</tr>
<tr>
    <td>Right</td><td>space</td>
</tr>
</table>

## Directional Button Games

<table>
<tr>
    <td>Left</td><td>ctrl</td>
</tr>
<tr>
    <td>Right</td><td>alt</td>
</tr>
<tr>
    <td>Up</td><td>Aa</td>
</tr>
<tr>
    <td>Down</td><td>opt</td>
</tr>
<tr>
    <td>Button</td><td>space</td>
</tr>
</table>

## 4 Button Games

Mickey & Donald, Squish

<table>
<tr>
    <td>Up</td><td>fn</td>
</tr>
<tr>
    <td>Down</td><td>ctrl</td>
</tr>
<tr>
    <td>Left</td><td>/</td>
</tr>
<tr>
    <td>Right</td><td>space</td>
</tr>
</table>

Black Jack

<table>
<tr>
    <td>Double Down</td><td>fn</td>
</tr>
<tr>
    <td>Bet x10 / Hit</td><td>ctrl</td>
</tr>
<tr>
    <td>Enter</td><td>enter</td>
</tr>
<tr>
    <td>Bet x1 / Stand</td><td>space</td>
</tr>
</table>

# Roms
The roms must be in .gw format. 

These need to be created using LCD-Game-Shrinker from the MAME rom and artwork files.

You can download LCD-Game-Shrinker from here:

https://github.com/bzhxx/LCD-Game-Shrinker

You need to set the resoultion in LCD-Game-Shrinker to 240x270.

In the file shrink_it.py change: 
```
gw_width=320
gw_height=240
```

to

```
gw_width=240
gw_height=270
```

Below is a list of the gw files required:

<table cellpadding="2" cellspacing="0">
<tr><td>Mame Rom</td><td>GW File</td></tr>
<tr><td>gnw_bjack</td><td>Game & Watch Black Jack.gw</td></tr>
<tr><td>gnw_bsweep</td><td>Game & Watch Bomb Sweeper.gw</td></tr>
<tr><td>gnw_dkong2</td><td>Game & Watch Donkey Kong II.gw</td></tr>
<tr><td>gnw_dkong</td><td>Game & Watch Donkey Kong.gw</td></tr>
<tr><td>gnw_gcliff</td><td>Game & Watch Gold Cliff.gw</td></tr>
<tr><td>gnw_ghouse</td><td>Game & Watch Green House.gw</td></tr>
<tr><td>gnw_mickdon</td><td>Game & Watch Mickey & Donald.gw</td></tr>
<tr><td>gnw_opanic</td><td>Game & Watch Oil Panic.gww</td></tr>
<tr><td>gnw_pinball</td><td>Game & Watch Pinball.gw</td></tr>
<tr><td>gnw_sbuster</td><td>Game & Watch Safe Buster.gw</td></tr>
<tr><td>gnw_squish</td><td>Game & Watch Squish.gw</td></tr>
<tr><td>gnw_zelda</td><td>Game & Watch Zelda.gw</td></tr>
</table>

Below is a link to a guide describing how to use LCD-Game-Shrinker to generate the files.

https://gist.github.com/DNA64/16fed499d6bd4664b78b4c0a9638e4ef

## Additional Steps for Multi Screen Games

LCD Game Shrinker will convert multi screen games into one screen games in portrait mode, so we need to do some additional steps when generating the gw files.

Below are instructions to fix oil panic. All other multi screen games will be similar.

Make a copy of LCD-Game-Shrinker to use for multi screen games.

In the file shrink_it.py set: 
```
gw_width=240
gw_height=270
```
In the custom directory, edit gnw_opanic.py

set rom.rotate to false
```
rom.rotate = False
```
Change rom.width_border_ratio from:
```
rom.width_border_ratio = 10/100
```
to:
```
rom.width_border_ratio = 0
```

## Black border between screens
If you run LCD Game Shrinker now there will be a black bar of about 10 pixels between the top and bottom screen.
The gw file will still work ok, but it is a good idea to remove it as it is wasting 10 pixels from the display.

To remove the black bar you need to:

- Extract the artwork zip file.
- Edit the default.lay file to remove the black bar.
- Zip the files again with the updated default.lay file.

In the default.lay file, find the view with the Backgrounds Only. (They usually have a height of 1669).

There is usually more than 1 background view. I am not sure which view LCD Game Shrinker uses so i was just updating all of them. They all use that same values so it is quick to update all of them at the same time.

```
<view name="Backgrounds Only">

<bounds x="32" y="33" width="1296" height="1669" />
	
	<element ref="Screen-Top">					<bounds x="32" y="33" width="1296" height="817" /></element>
	<screen index="0" blend="multiply">			<bounds x="1" y="9" width="1349" height="899" /></screen>
	<element ref="Screen-Top">					<bounds x="32" y="33" width="1296" height="817" /><color alpha="0.0" /></element>
	
	<element ref="Screen-Bottom">				<bounds x="32" y="885" width="1296" height="817" /></element>
	<screen index="1" blend="multiply">			<bounds x="-1" y="903" width="1371" height="878" /></screen>
	<element ref="Screen-Bottom">				<bounds x="32" y="885" width="1296" height="817" /><color alpha="0.00" /></element>
	<element ref="Balcony">				<bounds x="32" y="885" width="1296" height="817" /><color alpha="0.5" /></element>

</view>
```

New height: (Screen-Top + Screen-Bottom) 817 + 817 = 1634

Height difference: 1669 - 1634 = 35

Bounds height attribute is updated with the new height.

The height difference is removed from the y attribute of all the bottom screen elements.

```
<view name="Backgrounds Only">

<bounds x="32" y="33" width="1296" height="1634" />
	
	<element ref="Screen-Top">					<bounds x="32" y="33" width="1296" height="817" /></element>
	<screen index="0" blend="multiply">			<bounds x="1" y="9" width="1349" height="899" /></screen>
	<element ref="Screen-Top">					<bounds x="32" y="33" width="1296" height="817" /><color alpha="0.0" /></element>
	
	<element ref="Screen-Bottom">				<bounds x="32" y="850" width="1296" height="817" /></element>
	<screen index="1" blend="multiply">			<bounds x="-1" y="868" width="1371" height="878" /></screen>
	<element ref="Screen-Bottom">				<bounds x="32" y="850" width="1296" height="817" /><color alpha="0.00" /></element>
	<element ref="Balcony">				<bounds x="32" y="850" width="1296" height="817" /><color alpha="0.5" /></element>

</view>
```

# Building
Install the ESP-IDF framework. The version I used was v6.0.1.
https://docs.espressif.com/projects/esp-idf/en/stable/esp32s3/get-started/index.html

Make sure you can build the hello_world example project.

Download the code from this repo.

Use LCD-Game-Shrinker to generate the game files (see above) and place the gw files in the /gandw_cardputer/main/ directory.

Go back to /gandw_cardputer/ directory and open the terminal or cmd window in this directory.

## Linux

These instructions are for linux. If you are using windows follow the same steps you did when building the hello_world example project.

Run the export.sh script or get_idf if you set it up.

Export script should be similar to: 

```
. $HOME/esp/esp-idf/export.sh
```

Build: 

```
idf.py build
```

Then: 

```
idf.py -DMODEL=cardputer_multi_screen -p /dev/ttyACM0 flash
```

You can also monitor by adding monitor at the end: 

```
idf.py -DMODEL=cardputer_multi_screen -p /dev/ttyACM0 flash monitor 
```

Press Ctrl and ] to exit monitor.

If you are getting errors try a fullclean before building: 

```
idf.py fullclean
```

# Acknowledgements

## LCD-Game-Emulator
https://github.com/bzhxx/lcd-game-emulator

## Retro-Go
https://github.com/ducalex/retro-go

The LCD-Game-Emulator version used by the project was copied from Retro-Go because it contains additional code to handle the loading of the gw files.

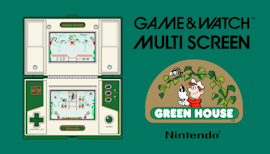
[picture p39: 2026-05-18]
assets/menu/handheld_multi_screen_dpad/bottom_green_house.png

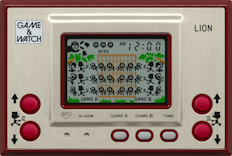
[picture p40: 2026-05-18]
assets/menu/handheld_single_screen_4_button/lion.png

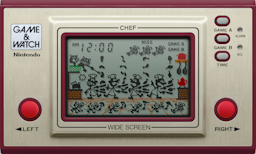
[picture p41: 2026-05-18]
assets/menu/handheld_single_screen_2_button/chef.png

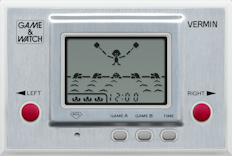
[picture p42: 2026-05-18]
assets/menu/handheld_single_screen_4_button/vermin.png

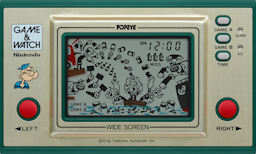
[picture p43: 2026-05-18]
assets/menu/handheld_single_screen_2_button/popeye.png

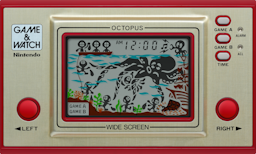
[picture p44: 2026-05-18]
assets/menu/handheld_single_screen_2_button/octopus.png

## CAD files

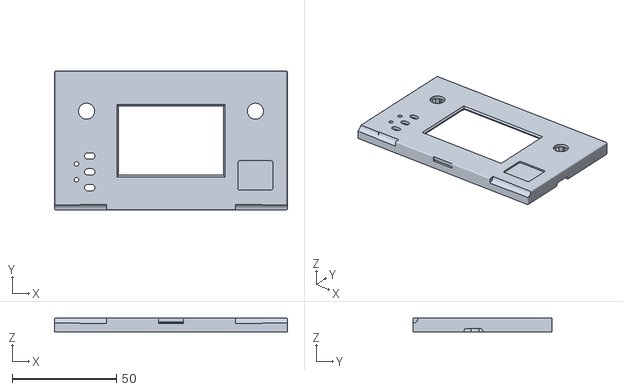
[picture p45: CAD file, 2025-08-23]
assets/3d_files/gandw_multi_screen_handheld/bottom_case_front_part_main.stl
112.0 x 67.0 x 6.80

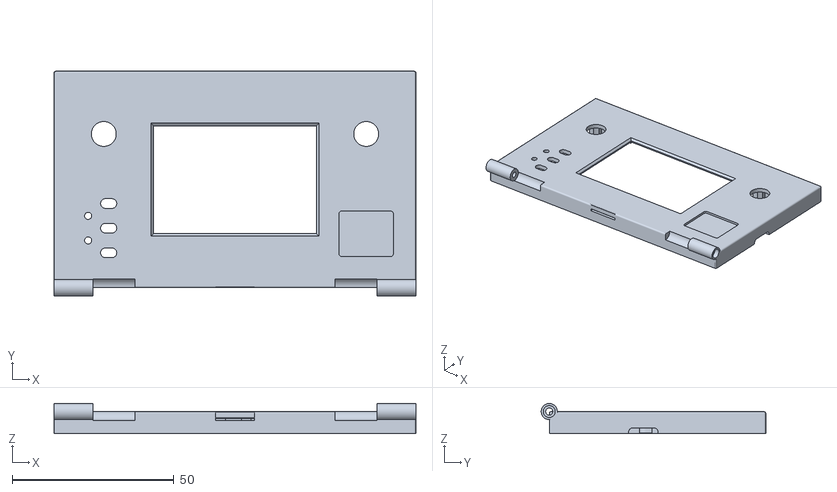
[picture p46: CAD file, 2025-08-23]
assets/3d_files/gandw_multi_screen_handheld/bottom_case_front_complete.stl
112.0 x 69.5 x 9.30

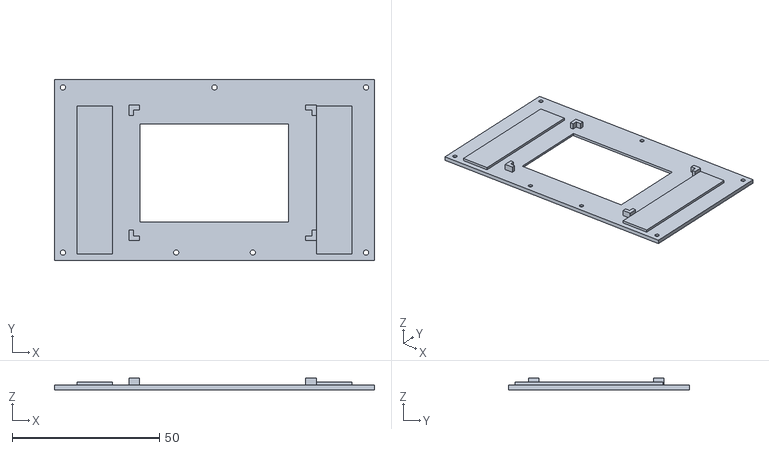
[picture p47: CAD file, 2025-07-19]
assets/3d_files/gandw_multi_screen_handheld/top_case_front_complete.stl
108.6 x 61.6 x 4.00

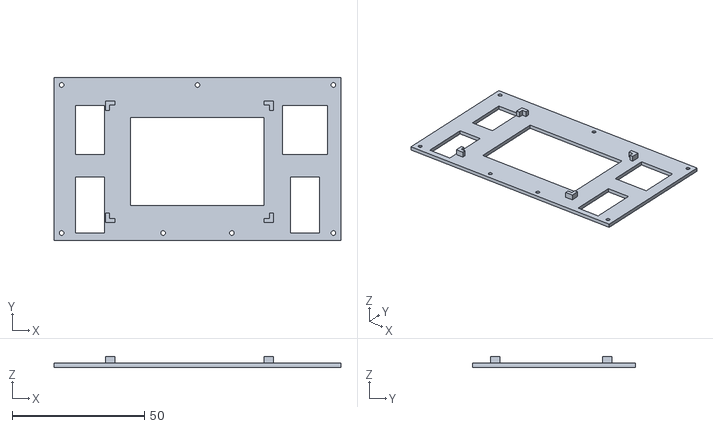
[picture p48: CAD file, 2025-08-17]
assets/3d_files/gandw_multi_screen_dpad_handheld/top_case_front_part_main.stl
108.6 x 61.6 x 4.00

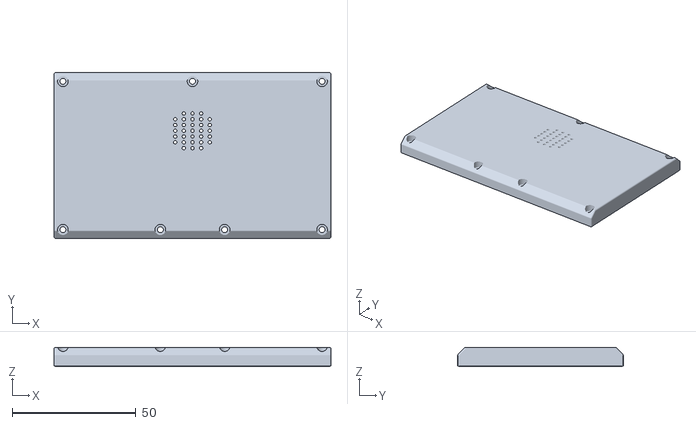
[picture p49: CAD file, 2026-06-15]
assets/3d_files/gandw_multi_screen_dpad_handheld/bottom_case_back.stl
112.0 x 67.0 x 7.80

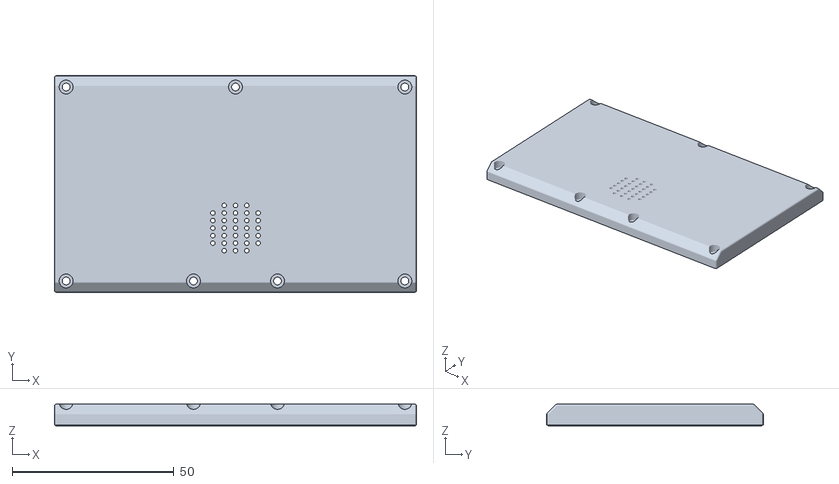
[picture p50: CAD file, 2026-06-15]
assets/3d_files/gandw_multi_screen_handheld/bottom_case_back.stl
112.0 x 67.0 x 6.80

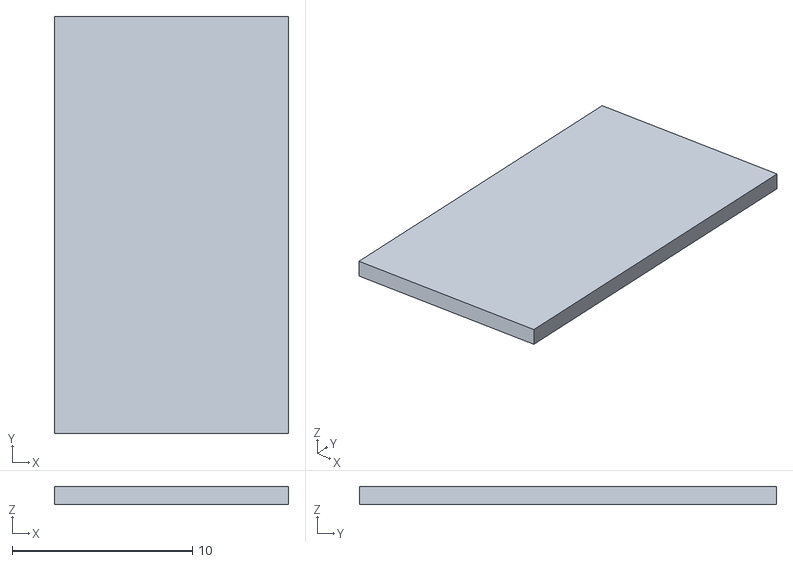
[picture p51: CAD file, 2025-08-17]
assets/3d_files/gandw_multi_screen_dpad_handheld/top_case_front_part_panel_1.stl
13.0 x 23.1 x 1.00

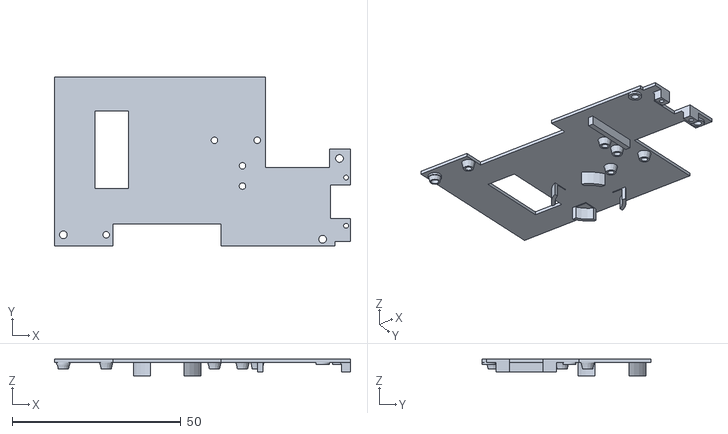
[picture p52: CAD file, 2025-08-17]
assets/3d_files/gandw_single_screen_4button_handheld/component_mount.stl
87.7 x 50.2 x 5.00

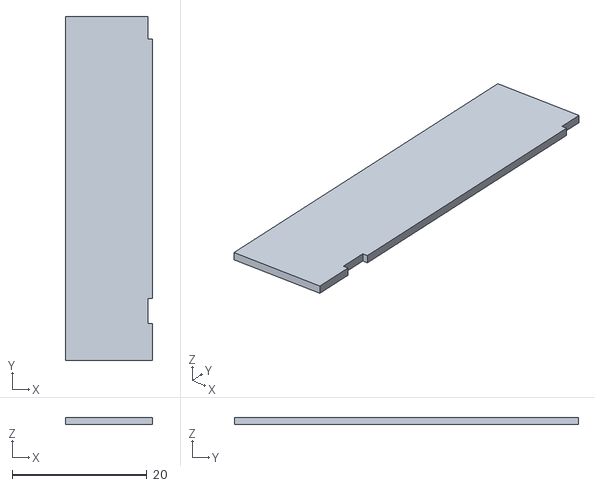
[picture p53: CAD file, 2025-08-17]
assets/3d_files/gandw_multi_screen_dpad_handheld/top_case_front_part_panel_3.stl
13.0 x 51.1 x 1.00

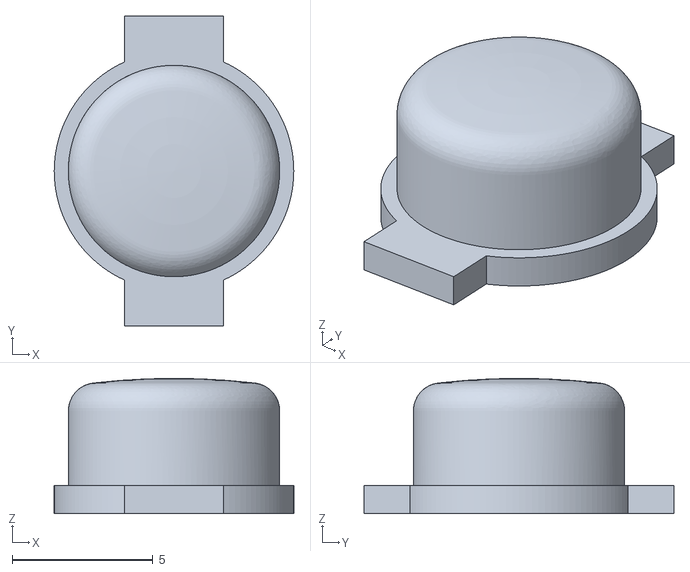
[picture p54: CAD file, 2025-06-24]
assets/3d_files/gandw_single_screen_4button_handheld/button.stl
8.50 x 11.0 x 4.80

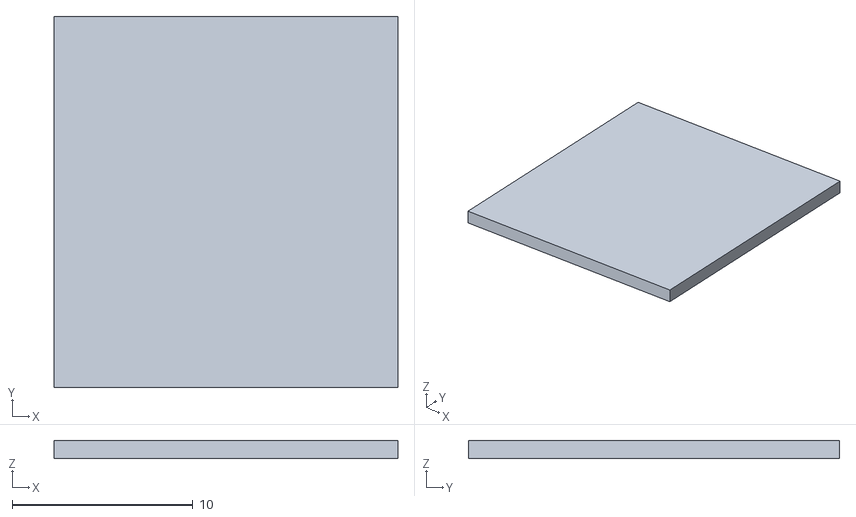
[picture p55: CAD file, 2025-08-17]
assets/3d_files/gandw_multi_screen_dpad_handheld/top_case_front_part_panel_2.stl
19.0 x 20.5 x 1.00

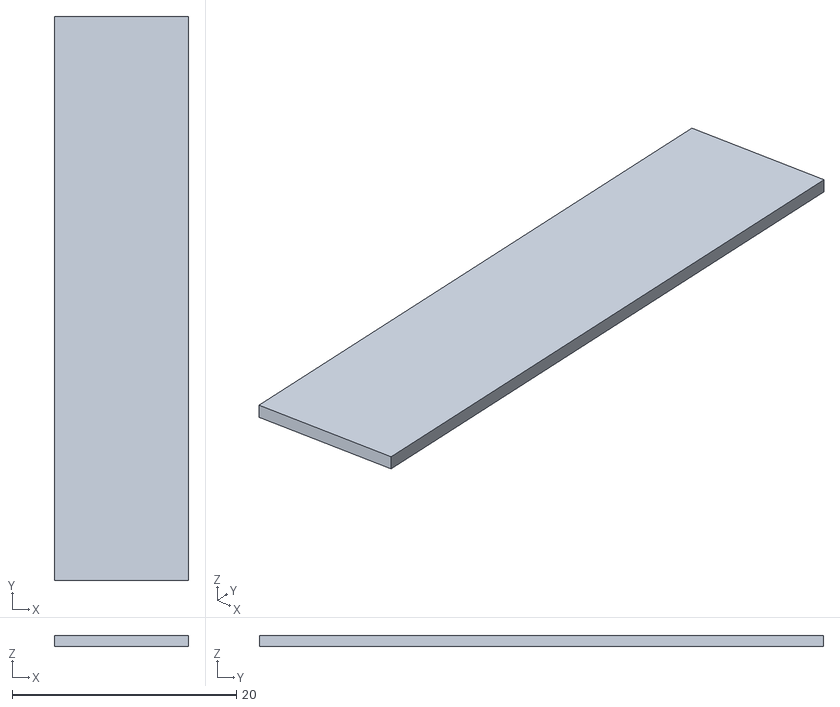
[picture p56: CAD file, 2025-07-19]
assets/3d_files/gandw_multi_screen_handheld/top_case_front_part_panel.stl
12.0 x 50.3 x 1.00

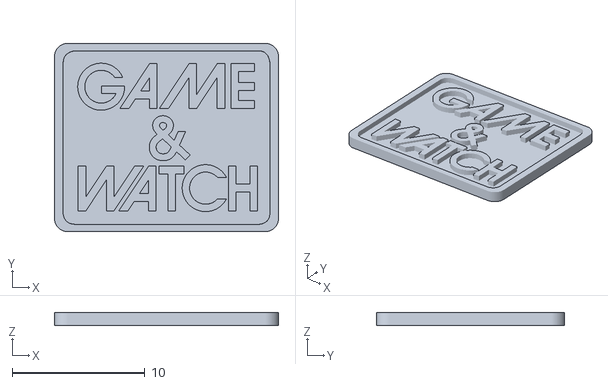
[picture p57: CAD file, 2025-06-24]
assets/3d_files/gandw_single_screen_4button_handheld/logo.stl
16.9 x 14.2 x 0.96

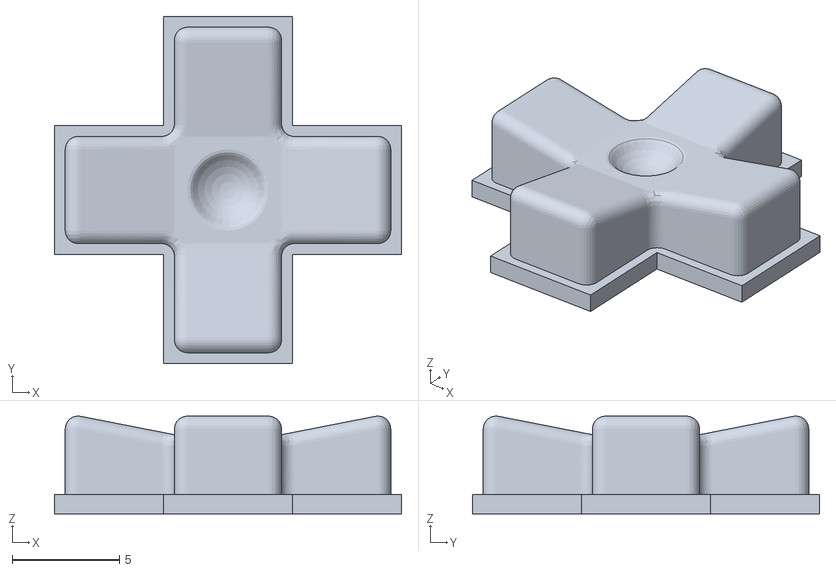
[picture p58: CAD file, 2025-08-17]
assets/3d_files/gandw_multi_screen_dpad_handheld/dpad.stl
16.2 x 16.2 x 4.57

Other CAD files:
assets/3d_files/gandw_multi_screen_dpad_handheld/bottom_case_front_part_main.stl
assets/3d_files/gandw_single_screen_4button_handheld/back.stl
assets/3d_files/gandw_single_screen_handheld/back.stl
assets/3d_files/gandw_single_screen_4button_handheld/front.stl
assets/3d_files/gandw_multi_screen_dpad_handheld/bottom_case_front_part_hinge.stl
assets/3d_files/gandw_multi_screen_dpad_handheld/top_case_back.stl
assets/3d_files/gandw_single_screen_4button_handheld/alarm_acl_button_spacer.stl
assets/3d_files/gandw_single_screen_4button_handheld/esp32_mount.stl
assets/3d_files/gandw_single_screen_4button_handheld/small_button.stl

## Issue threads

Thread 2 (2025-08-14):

Feature Enhancement: Add D-Pad for multi screen

Maverick-Shark, 2025-08-14:
Hi,

First of all, congrats!! It's an awesome work!!!

And now, my request: Add a D-Pad for multi-screen because could be awesome.

It could allow to play other multi screen game & watch games such us Donkey Kong, Donkey Kong II, Green House, Zelda or Gold Cliff.

Thanks and best regards,
Shark

VirtualDino, 2025-08-15:
In addition to this, I think it would be cool if there were a version for each of the different control schemes for Game & Watch games. For example, a 4 button device for playing games like Lion, Judge, or Egg. a D-pad for games like Donkey Kong Jr, etc.

I think this project is a fantasy way to help preserve these games since the original devices are literally rotting away. It would be great of you could make this addition.

Another suggestion: perhaps a custom PCB would make it easier to build? It would be cool to see something like that get implemented. And perhaps have some variants. For example a version like the one you built, and a secondary version that only uses external USB power (no battery inserted).

slowlane112, 2025-08-17:
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

I already have a 4 button handheld. You can see it here: [thingiverse](https://cdn.thingiverse.com/assets/e7/4a/d4/41/cd/large_display_Image10.jpg).

I just need to find time to get all the files together and upload them. Should be in the next week or so.

I would be great if somebody skilled enough can create a PCB. That would take this to the next level.

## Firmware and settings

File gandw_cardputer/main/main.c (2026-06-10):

#include "freertos/FreeRTOS.h"
#include <gw_system.h>
#include "button.h"
#include "keyboard.h"
#include "game.h"
#include "volume.h"
#include "battery.h"
#include "menu.h"
#include "audio.h"
#include "i2c.h"
#include "display.h"
#include "nvs.h"

static void display_volume_battery(unsigned short *framebuffer)
{
	if (volume_display_count > 0) {
		volume_display(framebuffer);
	}

	if (battery_display_count > 0) {
		battery_display(framebuffer);
	}
}

static void reset_system(unsigned short *framebuffer)
{
	display_blank_screen(framebuffer);
	esp_restart();
}

static void state_menu(unsigned short *framebuffer) {
	
	menu_index = game_get_selected();

	menu_update = true;
	
	while (menu_show) {
		
		menu_buttons_process();
		
		if (volume_display_count > 0) {
			volume_display_count--;
			if (volume_display_count == 0) {
				menu_update = true;
			}
		}

		if (battery_display_count > 0) {
			battery_display_count--;
			if (battery_display_count == 0) {
				menu_update = true;
			}
		}
		
		if (button_start_delay > 0) {
			button_start_delay--;
		}
			
		if (menu_update && !display_transfer_in_progress) {
			
			menu_display_item(framebuffer, menu_index);
			
			if (volume_display_count > 0 || battery_display_count > 0) {
				display_volume_battery(framebuffer);
			}

			display_render_screen(framebuffer);
			
			menu_update = false;
			
		}
		
		vTaskDelay(pdMS_TO_TICKS(10)); 
		
	}
	
}

static void state_game(unsigned short *framebuffer, uint16_t *audio_buffer) {
	
	size_t audio_buffer_size = GW_AUDIO_BUFFER_LENGTH * sizeof(uint16_t);
	
	game_load(menu_index);

	gw_system_romload();

	gw_system_sound_init();
	gw_system_config();
	gw_system_start();
	gw_system_reset();
	
	while (!menu_show) {

		if (volume_display_count > 0) {
			volume_display_count--;
		}

		if (battery_display_count > 0) {
			battery_display_count--;
		}
		
		if (button_start_delay > 0) {
			button_start_delay--;
		}

		gw_system_run(GW_SYSTEM_CYCLES);

		// lcd
		if (!display_transfer_in_progress) {

			display_transfer_in_progress = true;

			gw_system_blit(framebuffer);

			if (volume_display_count > 0 || battery_display_count > 0) {
				display_volume_battery(framebuffer);
			}

			display_render_screen(framebuffer);
			
		}

		// audio
		for (size_t i = 0; i < GW_AUDIO_BUFFER_LENGTH; i++)
		{
			audio_buffer[i] = (gw_audio_buffer[i] > 0) * volume;
		}

		size_t bytes_written;

		i2s_channel_write(i2s_audio_handle, audio_buffer, audio_buffer_size, &bytes_written, portMAX_DELAY);

		gw_audio_buffer_copied = true;
		
   }
	
}

void app_main(void)
{
	uint16_t *framebuffer = (uint16_t *)heap_caps_malloc(GW_SCREEN_WIDTH * GW_SCREEN_HEIGHT * sizeof(uint16_t), MALLOC_CAP_DMA | MALLOC_CAP_INTERNAL);
	uint16_t audio_buffer[GW_AUDIO_BUFFER_LENGTH];

	i2c_init();
	audio_init();
	display_init();
	keyboard_init();
	nvs_init();
	
#if defined(MODEL_CARDPUTER_MULTI_SCREEN)	
	display_setup_top_screen(framebuffer);
#endif

	// blank screen at start up
	display_blank_screen(framebuffer);	
	
	volume_read();

	battery_get_level();
	
	state_menu(framebuffer);
	
	state_game(framebuffer, audio_buffer);
	
	reset_system(framebuffer);
	
}

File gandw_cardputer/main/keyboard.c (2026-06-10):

#include "freertos/FreeRTOS.h"
#include "driver/gpio.h"
#include "i2c.h"

// ###### Cardputer adv ######

#define ADV_INT_PIN				11
#define ADV_TCA8418_ADDR		0x34
#define ADV_REG_CFG				0x01
#define ADV_REG_INT_STAT		0x02
#define ADV_REG_KEY_LCK_EC		0x03
#define ADV_REG_KEY_EVENT		0x04
#define ADV_REG_INT_EN			0x07
#define ADV_REG_KP_GPIO1		0x1D
#define ADV_REG_KP_GPIO2		0x1E
#define ADV_REG_KP_GPIO3		0x1F
#define ADV_I2C_MASTER_TIMEOUT	50
#define ADV_NUM_ROWS			8
#define ADV_NUM_COLS			9

static uint8_t adv_key_map_state[ADV_NUM_ROWS][ADV_NUM_COLS] = {{0}};
static QueueHandle_t adv_key_event_queue = NULL;
static char adv_key_map[ADV_NUM_ROWS][ADV_NUM_COLS] = {
	[0][0] = '`',	
	[4][0] = '1',
	[2][1] = '2',
	[6][1] = '3',
	[4][2] = '4',
	[0][3] = '5',
	[6][3] = '6',
	[2][4] = '7',
	[0][5] = '8',
	[4][5] = '9',
	[2][6] = '0',
	[6][6] = '_',
	[4][7] = '=',
	[0][8] = 0x87, // Backspace
	
	[1][0] = 0x88, // Tab
	[5][0] = 'Q',
	[3][1] = 'W',	
	[7][1] = 'E',
	[5][2] = 'R',	
	[1][3] = 'T',
	[7][3] = 'Y',	
	[3][4] = 'U',
	[1][5] = 'I',	
	[5][5] = 'O',
	[3][6] = 'P',	
	[7][6] = '[',
	[5][7] = ']',	
	[1][8] = '\\',
	
	[2][0] = 0x85, // Fn
	[6][0] = 0x84, // Aa
	[4][1] = 'A',	
	[0][2] = 'S',
	[6][2] = 'D',	
	[2][3] = 'F',
	[0][4] = 'G',	
	[4][4] = 'H',
	[2][5] = 'J',	
	[6][5] = 'K',
	[4][6] = 'L',	
	[0][7] = ';',
	[6][7] = '\'',	
	[2][8] = 0x86, // Enter
	
	[3][0] = 0x80, // Ctrl
	[7][0] = 0x82, // opt
	[5][1] = 0x81, // Alt
	[1][2] = 'Z',     
	[7][2] = 'X',
	[3][3] = 'C',
	[1][4] = 'V',
	[5][4] = 'B',
	[3][5] = 'N',
	[7][5] = 'M',
	[5][6] = ',',
	[1][7] = '.',
	[7][7] = '/',
	[3][8] = 0x20 // Space
};

static esp_err_t adv_tca8418_write_reg(uint8_t reg_addr, uint8_t data) {
	uint8_t write_buf[2] = {
		reg_addr,
		data
	};

	return i2c_master_transmit(
		g_tca8418_dev,
		write_buf,
		sizeof(write_buf),
		ADV_I2C_MASTER_TIMEOUT
	);
}

static esp_err_t adv_tca8418_read_mult_reg(uint8_t reg_addr, uint8_t *data_buf, size_t len) {
	return i2c_master_transmit_receive(
		g_tca8418_dev,
		&reg_addr,
		1,
		data_buf,
		len,
		ADV_I2C_MASTER_TIMEOUT
	);
}

static esp_err_t adv_tca8418_read_reg(uint8_t reg, uint8_t *data) {
	return i2c_master_transmit_receive(
		g_tca8418_dev,
		&reg,
		1,
		data,
		1,
		100
	);
}

static void adv_keycode_to_rc(uint8_t keycode, int *r, int *c) {
	if (keycode == 0) {
		*r = -1;
		*c = -1;
		return;
	}

	*r = (keycode - 1) % 8;
	*c = (keycode - 1) / 8;
}

static void adv_tca8418_event_task(void *arg) {
	uint32_t event_val;
	uint8_t key_event_byte;

	while (1) {

		if (xQueueReceive(adv_key_event_queue, &event_val, portMAX_DELAY) == pdTRUE) {
			
			uint8_t count_and_lck;

			while (adv_tca8418_read_mult_reg(ADV_REG_KEY_LCK_EC, &count_and_lck,1) == ESP_OK) {
				
				uint8_t event_count = count_and_lck & 0x0F;

				if (event_count == 0) {
					adv_tca8418_write_reg(ADV_REG_INT_STAT, 0xFF);
					break;
				}

				if (adv_tca8418_read_mult_reg(ADV_REG_KEY_EVENT, &key_event_byte, 1) == ESP_OK) {
					
					bool is_pressed = (key_event_byte & 0x80) ? true : false;
					uint8_t key_code = key_event_byte & 0x7F;

					int r;
					int c;

					adv_keycode_to_rc(key_code, &r, &c);

					if (r >= 0 &&
						r < ADV_NUM_ROWS &&
						c >= 0 &&
						c < ADV_NUM_COLS)
					{
						adv_key_map_state[r][c] =
							is_pressed ? 1 : 0;
					}
				}
			}
		}
		
	}
}

static void IRAM_ATTR adv_tca8418_isr_handler(void *arg) {
	
	BaseType_t xHigherPriorityTaskWoken = pdFALSE;

	xQueueSendFromISR(adv_key_event_queue, &(uint32_t){1}, &xHigherPriorityTaskWoken);

	if (xHigherPriorityTaskWoken == pdTRUE) {
		portYIELD_FROM_ISR();
	}
}

static void adv_keyboard_setup(void) {
	
	adv_tca8418_write_reg(ADV_REG_CFG, 0x01);
	adv_tca8418_write_reg(ADV_REG_KP_GPIO1, 0xFF);
	adv_tca8418_write_reg(ADV_REG_KP_GPIO2, 0xFF);
	adv_tca8418_write_reg(ADV_REG_KP_GPIO3, 0x03);

	uint8_t stat;

	adv_tca8418_read_reg(ADV_REG_INT_STAT, &stat);

	adv_tca8418_write_reg(ADV_REG_INT_STAT, 0xFF);

	adv_key_event_queue = xQueueCreate(10, sizeof(uint32_t));

	xTaskCreate(adv_tca8418_event_task, "adv_tca_evt_task", 4096, NULL, 10, NULL);

	gpio_config_t io_conf = {
		.intr_type = GPIO_INTR_NEGEDGE,
		.mode = GPIO_MODE_INPUT,
		.pin_bit_mask = (1ULL << ADV_INT_PIN),
		.pull_up_en = 1,
	};

	gpio_config(&io_conf);

	if (gpio_get_level(ADV_INT_PIN) == 0) {
		uint32_t dummy = 0;
		xQueueSend(adv_key_event_queue, &dummy, 0);
	}

	adv_tca8418_write_reg(ADV_REG_INT_EN, 0x02);

	static bool isr_service_installed = false;

	if (!isr_service_installed) {
		gpio_install_isr_service(0);
		isr_service_installed = true;
	}

	gpio_isr_handler_add(ADV_INT_PIN, adv_tca8418_isr_handler, NULL);
}

// ###### Cardputer Original ######

#define ORG_GPIO_74HC138_A0		GPIO_NUM_8
#define ORG_GPIO_74HC138_A1		GPIO_NUM_9
#define ORG_GPIO_74HC138_A2		GPIO_NUM_11
#define ORG_NUM_COLUMNS			7

const gpio_num_t column_gpios[ORG_NUM_COLUMNS] = {
	GPIO_NUM_13,
	GPIO_NUM_15,
	GPIO_NUM_3,
	GPIO_NUM_4,
	GPIO_NUM_5,
	GPIO_NUM_6,
	GPIO_NUM_7
};
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

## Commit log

2025-06-24 Added handheld version
    [alarm_acl_button_spacer.stl, back.stl, button.stl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]
2025-06-24 Update LCD wiring and comment battery testing code
2025-06-28 Update instructions, 3d files and fixes for some games
    [component_mount.stl]
2025-07-19 Added multi screen handheld
    [alarm_acl_button_spacer.stl, bottom_case_back.stl, bottom_case_front_complete.stl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]
2025-08-17 Added multi screen d-pad handheld
    [alarm_acl_button_spacer.stl, bottom_case_back.stl, bottom_case_front_part_hinge.stl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]
2025-08-23 Add small gap between shell and screen
    [bottom_case_front_complete.stl, bottom_case_front_part_main.stl, front.stl]
2025-08-23 Initial 4 button handheld files
    [alarm_acl_button_spacer.stl, back.stl, button.stl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]
2025-08-24 Added 4 button files
2025-11-24 Added 4 button with menu.
    [partitions.csv]
2025-12-12 Added menu and game fixes
    [partitions.csv]
2025-12-23 Added menu
    [partitions.csv]
2025-12-28 Cardputer multi screen
    [partitions.csv]
2025-12-29 Update reset code to use timer
    [button.c, keyboard.c]
2026-05-19 Update i2c driver
2026-06-10 Updated to ESP‑IDF 6.0 and added support for ST7789V screens
    [partitions.csv]
2026-06-15 increase back panel screw hole size
    [back.stl, bottom_case_back.stl]
2026-08-24 Update time and alarm processing. Fix battery icon.
    [battery.c, gw_system.h]
